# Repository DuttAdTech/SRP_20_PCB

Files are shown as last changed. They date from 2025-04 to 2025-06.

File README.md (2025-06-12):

### Changes Suggested by Team
- Add Debug Headers for UART Lines for GSM.
- LORA Module Footprint adjust for Hand Soldering.
- Check SRAM Compatibility - 2 MBit.
- Add Resettable Fuse after SM712 Protection Diode on MB Lines.
- Display connector change in PCB.
- PCB partision layer change (edge cut).
- Make LDO based power supply.
- SDA SCL of ADS1115 need to connected properly.
- Vbat pin of the battery measurement need to connected to the MCU.
- Add 100uF capacitor(x2) in GSM.
- Logic level shifter footprint should be SC70.
- Ground of the optocoupler and Trip should be different
- Voltage for the TFT display should be checked before doing PCB connections.

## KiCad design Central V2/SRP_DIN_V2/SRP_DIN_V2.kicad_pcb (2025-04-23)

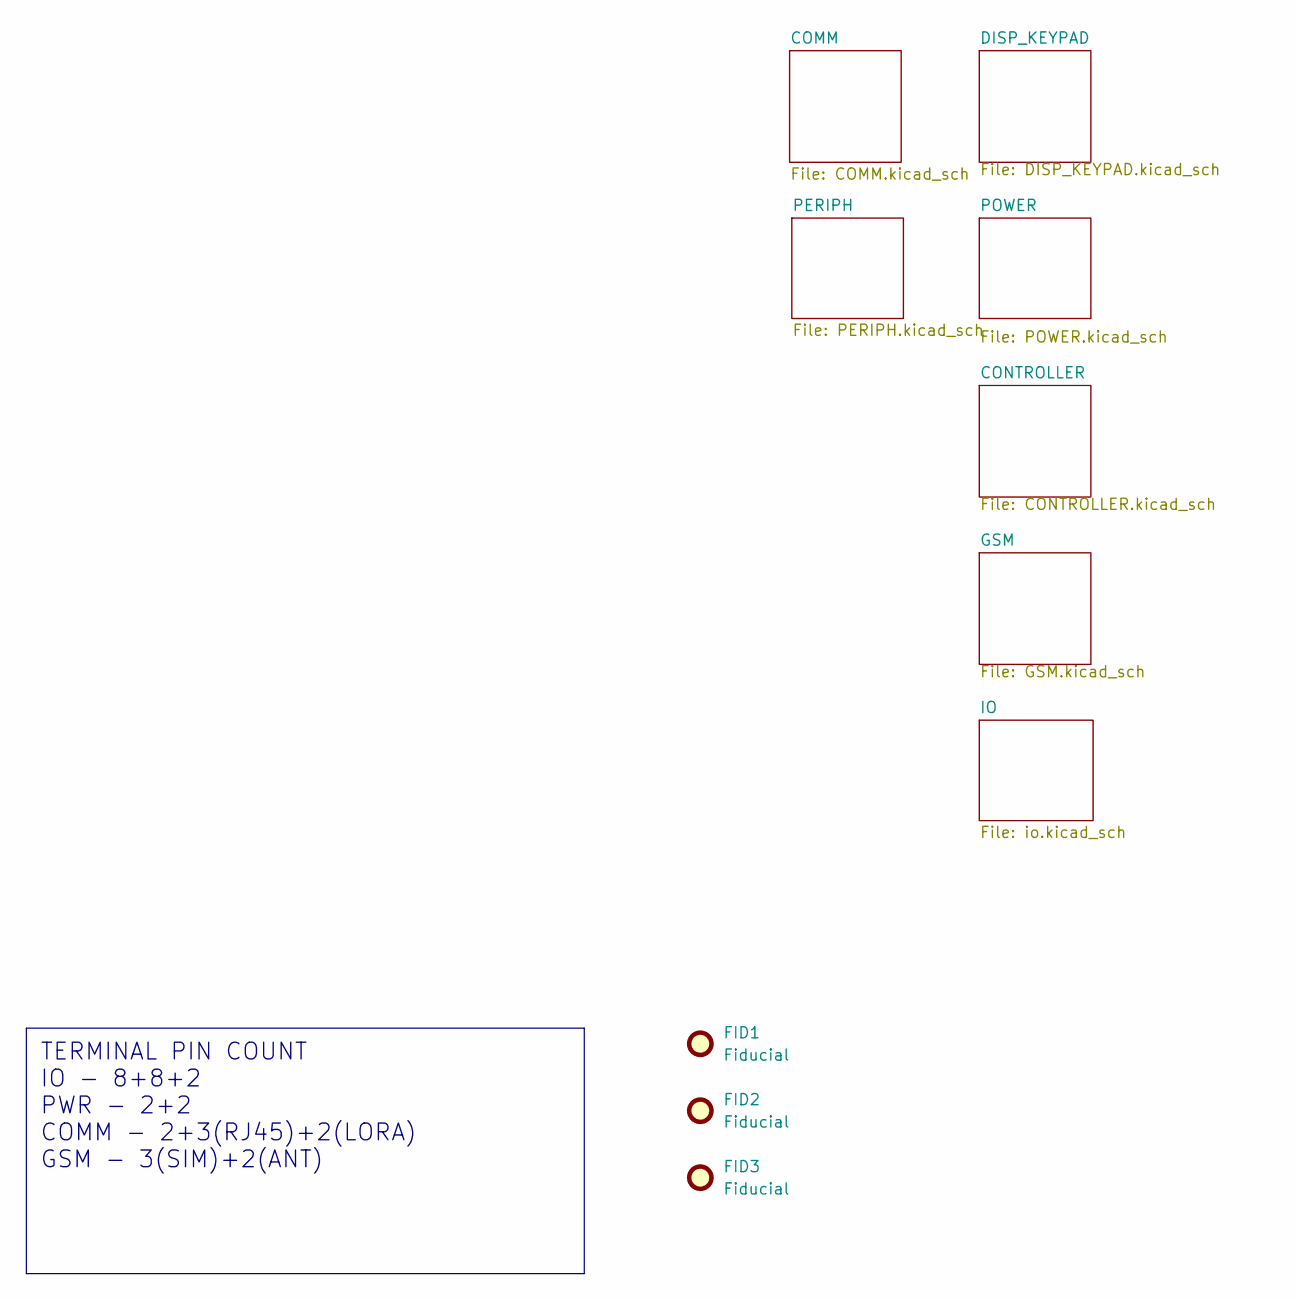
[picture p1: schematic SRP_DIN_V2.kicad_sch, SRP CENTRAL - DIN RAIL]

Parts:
FID1, FID2, FID3: Fiducial; Fiducial_1mm_Mask2mm

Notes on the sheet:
TERMINAL PIN COUNT IO - 8+8+2 PWR - 2+2 COMM - 2+3(RJ45)+2(LORA) GSM - 3(SIM)+2(ANT)

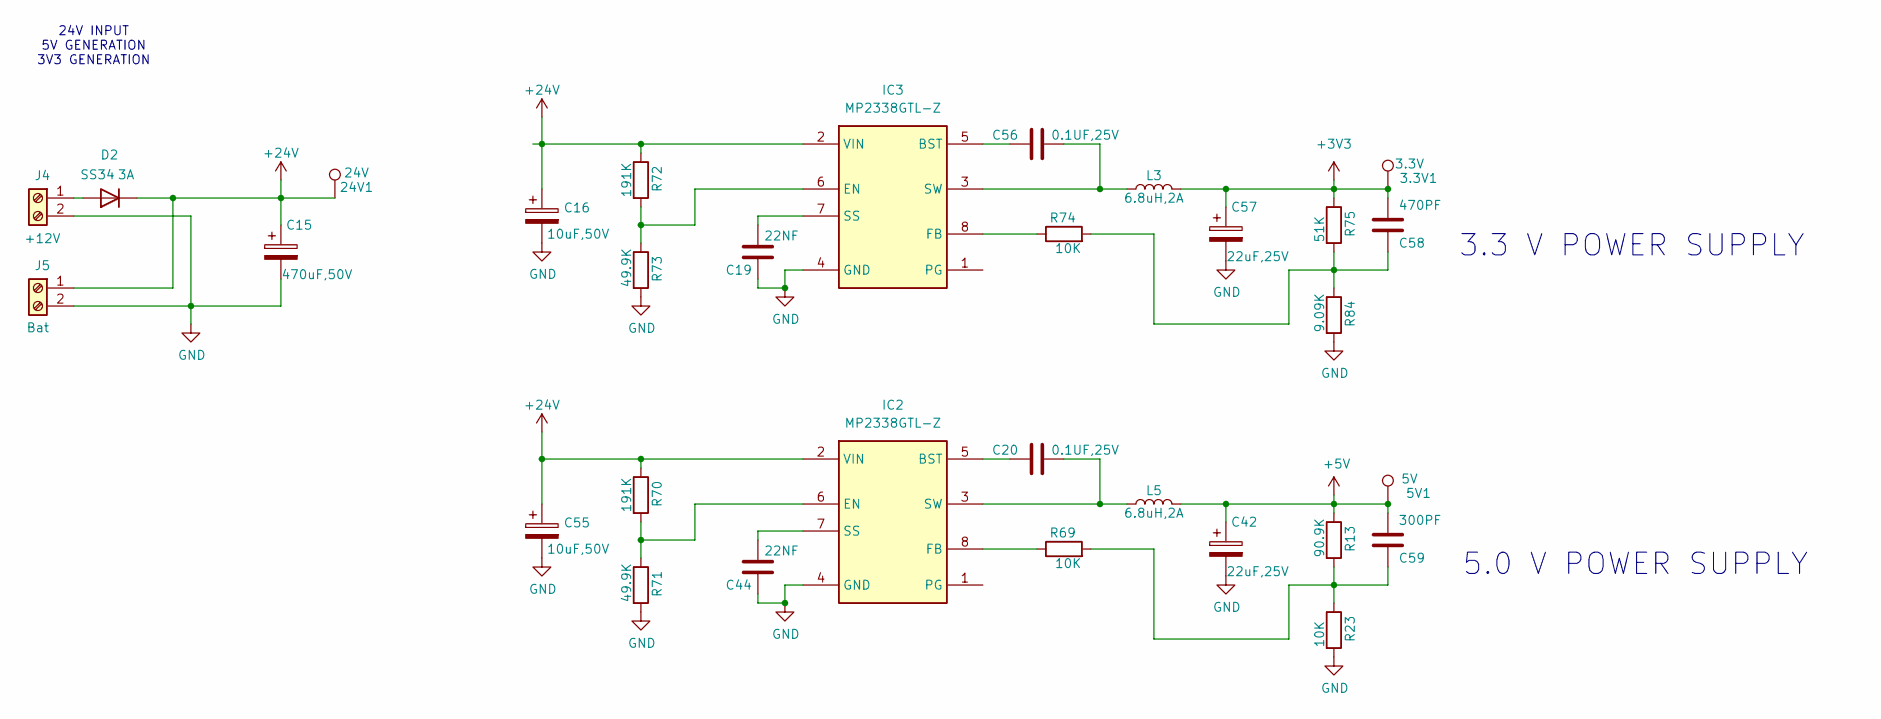
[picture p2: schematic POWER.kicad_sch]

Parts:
3.3V1: 3.3V; TestPoint_Pad_1.0x1.0mm
5V1: 5V; TestPoint_Pad_1.0x1.0mm
24V1: 24V; TestPoint_Pad_1.0x1.0mm
C15: 470uF,50V; CP_Elec_10x10.5
C16, C55: 10uF,50V; CP_Elec_8x5.4
C19, C44: 22NF; C_0805_2012Metric
C20, C56: 0.1UF,25V; C_0805_2012Metric
C42, C57: 22uF,25V; CP_Elec_6.3x5.3
C58: 470PF; C_0805_2012Metric
C59: 300PF; C_0805_2012Metric
D2: SS34; D_SMA
IC2, IC3: MP2338GTL-Z; SOT-583-8; Mouser Part Number 946-MP2338GTL-Z
J4: +12V; TerminalBlock_Phoenix_MKDS-3-2-5.08_1x02_P5.08mm_Horizontal
J5: Bat; TerminalBlock_Phoenix_MKDS-3-2-5.08_1x02_P5.08mm_Horizontal
L3, L5: 6.8uH,2A; L_2010_5025Metric
R13: 90.9K; R_0805_2012Metric_Pad1.20x1.40mm_HandSolder
R23, R69, R74: 10K; R_0805_2012Metric_Pad1.20x1.40mm_HandSolder
R70, R72: 191K; R_0805_2012Metric_Pad1.20x1.40mm_HandSolder
R71, R73: 49.9K; R_0805_2012Metric_Pad1.20x1.40mm_HandSolder
R75: 51K; R_0805_2012Metric_Pad1.20x1.40mm_HandSolder
R84: 9.09K; R_0805_2012Metric_Pad1.20x1.40mm_HandSolder

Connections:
+3V3: 3.3V1.1, C57.1, C58.2, L3.2, R75.1; also elsewhere on the board
+5V: 5V1.1, C42.1, C59.2, L5.2, R13.1; also elsewhere on the board
+24V: 24V1.1, C15.1, C16.1, C55.1, D2.1 (K), IC2.2 (VIN), IC3.2 (VIN), J5.1, R70.1, R72.1; also elsewhere on the board
GND: C15.2, C16.2, C19.1, C42.2, C44.1, C55.2, C57.2, IC2.4 (GND), IC3.4 (GND), J4.2, J5.2, R23.2, R71.2, R73.2, R84.2; also elsewhere on the board
unnamed: C58.1, R74.2, R75.2, R84.1
unnamed: C59.1, R13.2, R23.1, R69.2
unnamed: D2.2 (A), J4.1
unnamed: C20.1, IC2.5 (BST)
unnamed: IC2.6 (EN), R70.2, R71.1
unnamed: IC2.8 (FB), R69.1
unnamed: C44.2, IC2.7 (SS)
unnamed: C20.2, IC2.3 (SW), L5.1
unnamed: C56.1, IC3.5 (BST)
unnamed: IC3.6 (EN), R72.2, R73.1
unnamed: IC3.8 (FB), R74.1
unnamed: C19.2, IC3.7 (SS)
unnamed: C56.2, IC3.3 (SW), L3.1

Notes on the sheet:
3.3 V POWER SUPPLY
5.0 V POWER SUPPLY
24V INPUT 5V GENERATION 3V3 GENERATION

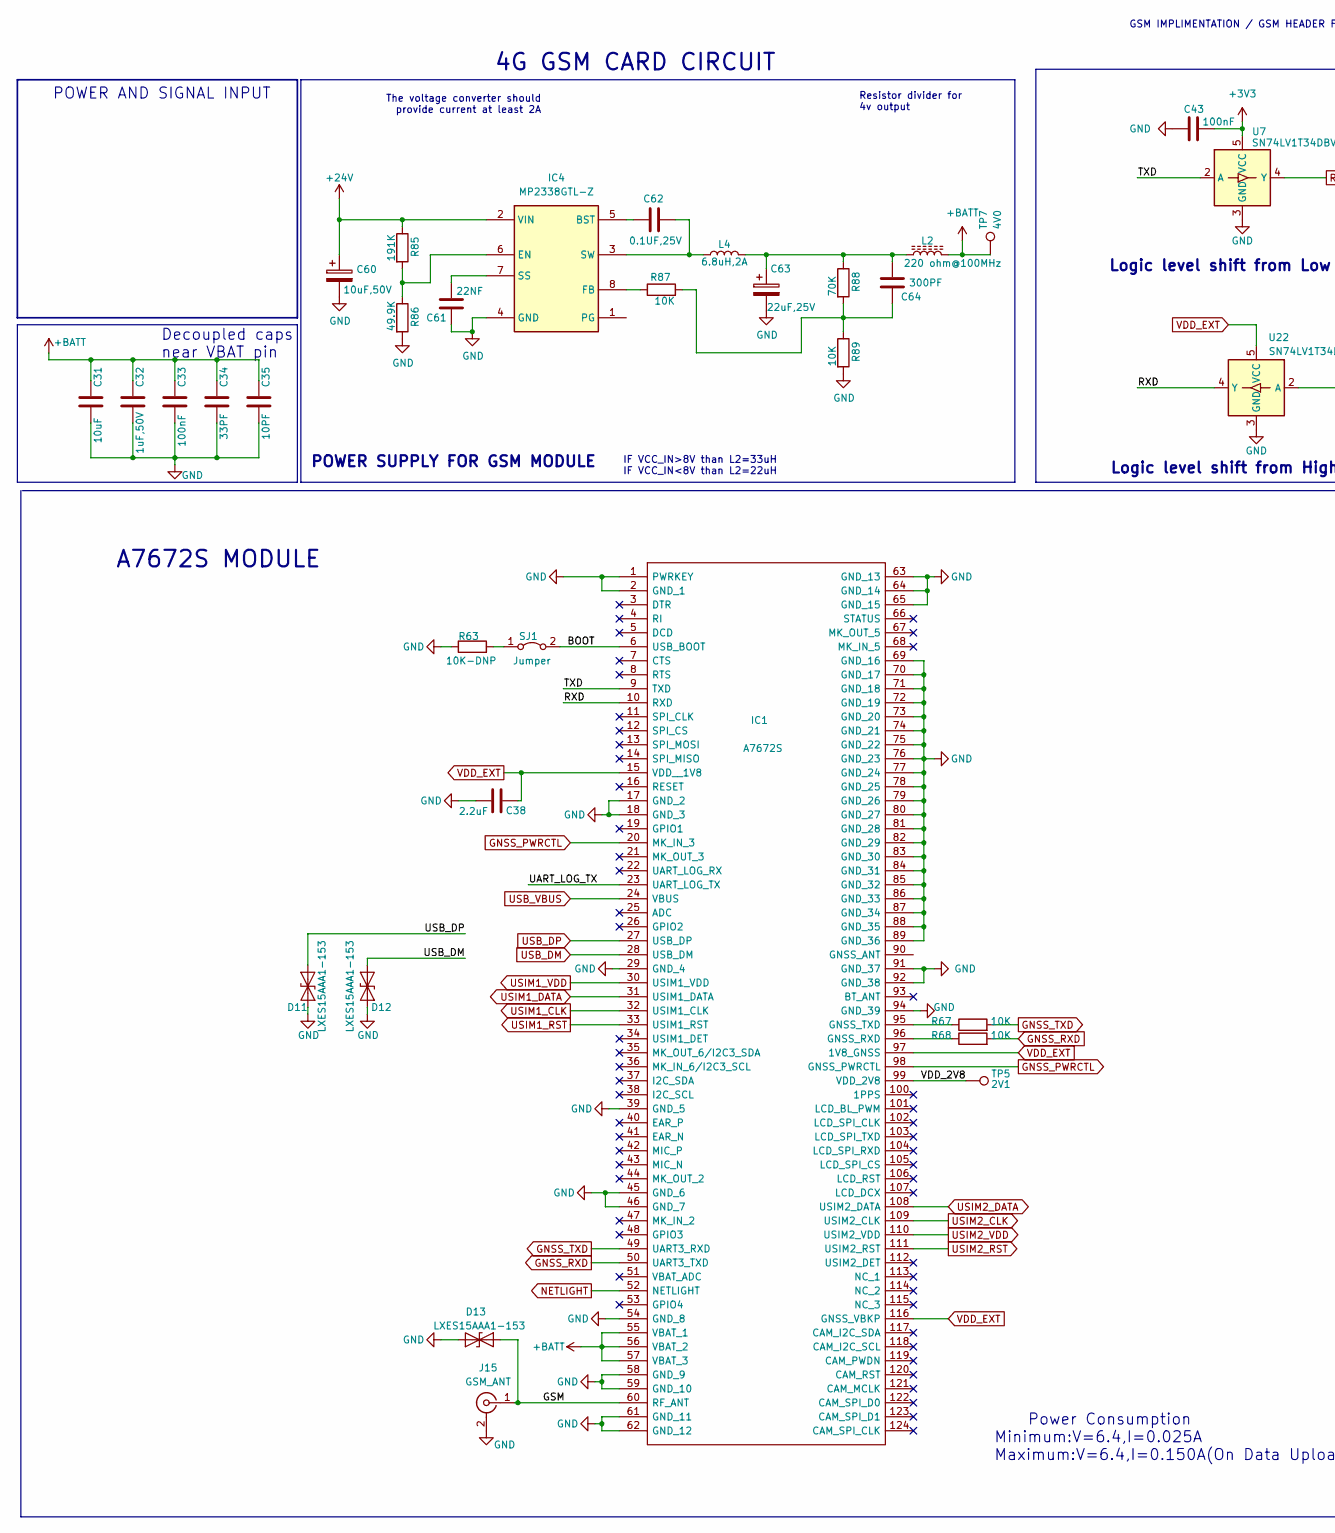
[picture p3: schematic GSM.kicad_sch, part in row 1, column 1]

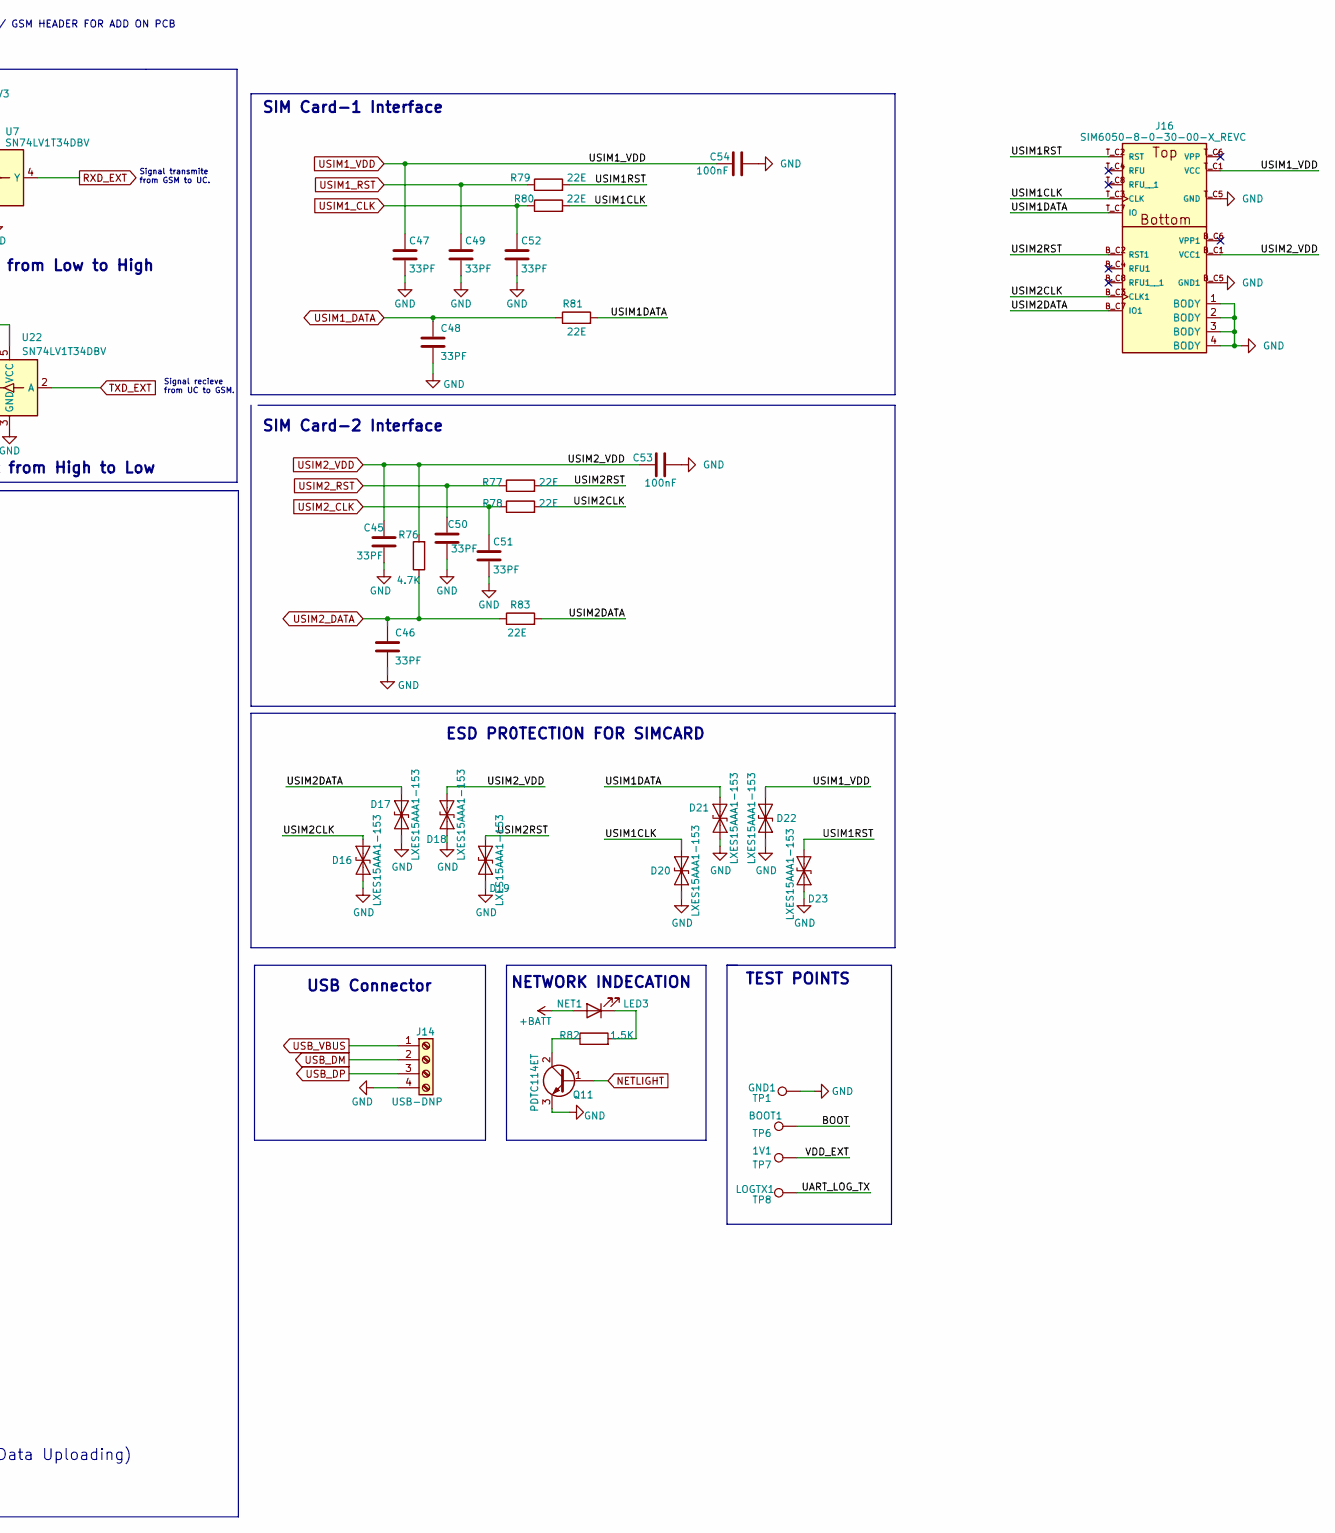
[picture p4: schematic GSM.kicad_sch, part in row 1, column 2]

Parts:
1V1, 4V0: TP7; TestPoint_Pad_1.0x1.0mm
2V1: TP5; TestPoint_Pad_1.0x1.0mm
BOOT1: TP6; TestPoint_Pad_1.0x1.0mm
C31: 10uF; C_0805_2012Metric
C32: 1uF,50V; C_0805_2012Metric
C33, C43, C53, C54: 100nF; C_0805_2012Metric
C34, C45, C46, C47, C48, C49, C50, C51, C52: 33PF; C_0805_2012Metric
C35: 10PF; C_0805_2012Metric
C38: 2.2uF; C_0805_2012Metric
C60: 10uF,50V; CP_Elec_6.3x5.3
C61: 22NF; C_0805_2012Metric
C62: 0.1UF,25V; C_0805_2012Metric
C63: 22uF,25V; CP_Elec_6.3x5.3
C64: 300PF; C_0805_2012Metric
D11, D12, D13, D16, D17, D18, D19, D20, D21, D22, D23: LXES15AAA1-153; D_0402_1005Metric_Pad0.77x0.64mm_HandSolder
GND1: TP1; TestPoint_Pad_1.0x1.0mm
IC1: A7672S; A7672SA; Manufacturer_Part_Number A7672SA
IC4: MP2338GTL-Z; SOT-583-8; Mouser Part Number 946-MP2338GTL-Z
J14: USB-DNP; PinHeader_1x04_P2.54mm_Vertical
J15: GSM_ANT; SMA_Amphenol_901-144_Vertical
J16: SIM6050-8-0-30-00-X_REVC; GCT_SIM6050-8-0-30-00-X_REVC
L2: 220 ohm@100MHz; L_0805_2012Metric
L4: 6.8uH,2A; L_2010_5025Metric
LOGTX1: TP8; TestPoint_Pad_1.0x1.0mm
NET1: LED3; LED_0805_2012Metric_Pad1.15x1.40mm_HandSolder
Q11: PDTC114ET; SOT-23
R63: 10K-DNP; R_0805_2012Metric
R67, R68: 10K; R_0805_2012Metric
R76: 4.7K; R_0805_2012Metric
R77, R78, R79, R80, R81, R83: 22E; R_0805_2012Metric
R82: 1.5K; R_0805_2012Metric
R85: 191K; R_0805_2012Metric_Pad1.20x1.40mm_HandSolder
R86: 49.9K; R_0805_2012Metric_Pad1.20x1.40mm_HandSolder
R87, R89: 10K; R_0805_2012Metric_Pad1.20x1.40mm_HandSolder
R88: 70K; R_0805_2012Metric_Pad1.20x1.40mm_HandSolder
SJ1: Jumper; SolderJumper-2_P1.3mm_Open_Pad1.0x1.5mm
U7, U22: SN74LV1T34DBV; SOT-23-5

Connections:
+3V3: C43.2, U7.5 (VCC); also elsewhere on the board
+24V: C60.1, IC4.2 (VIN), R85.1; also elsewhere on the board
+BATT: 4V0.1, C31.1, C32.1, C33.1, C34.1, C35.1, IC1.55 (VBAT_1), IC1.56 (VBAT_2), IC1.57 (VBAT_3), L2.2, NET1.2 (A)
/GSM/BOOT: BOOT1.1, IC1.6 (USB_BOOT), SJ1.2 (B)
/GSM/GSM: D13.1 (A1), IC1.60 (RF_ANT), J15.1 (In)
/GSM/RXD: IC1.10 (RXD), U22.4 (Y)
/GSM/TXD: IC1.9 (TXD), U7.2 (A)
/GSM/UART_LOG_TX: IC1.23 (UART_LOG_TX), LOGTX1.1
/GSM/USIM1CLK: D20.2 (A2), J16.T_C3 (CLK), R80.2
/GSM/USIM1DATA: D21.2 (A2), J16.T_C7 (IO), R81.2
/GSM/USIM1RST: D23.2 (A2), J16.T_C2 (RST), R79.2
/GSM/USIM2CLK: D16.2 (A2), J16.B_C3 (CLK1), R78.2
/GSM/USIM2DATA: D17.2 (A2), J16.B_C7 (IO1), R83.2
/GSM/USIM2RST: D19.2 (A2), J16.B_C2 (RST1), R77.2
/GSM/VDD_2V8: 2V1.1, IC1.99 (VDD_2V8)
GND: C31.2, C32.2, C33.2, C34.2, C35.2, C38.2, C43.1, C45.2, C46.2, C47.2, C48.2, C49.2, C50.2, C51.2, C52.2, C53.2, C54.2, C60.2, C61.1, C63.2, D11.1 (A1), D12.1 (A1), D13.2 (A2), D16.1 (A1), D17.1 (A1), D18.1 (A1), D19.1 (A1), D20.1 (A1), D21.1 (A1), D22.1 (A1), D23.1 (A1), GND1.1, IC1.1 (PWRKEY), IC1.2 (GND_1), IC1.17 (GND_2), IC1.18 (GND_3), IC1.29 (GND_4), IC1.39 (GND_5), IC1.45 (GND_6), IC1.46 (GND_7), IC1.54 (GND_8), IC1.58 (GND_9), IC1.59 (GND_10), IC1.61 (GND_11), IC1.62 (GND_12), IC1.63 (GND_13), IC1.64 (GND_14), IC1.65 (GND_15), IC1.69 (GND_16), IC1.70 (GND_17), IC1.71 (GND_18), IC1.72 (GND_19), IC1.73 (GND_20), IC1.74 (GND_21), IC1.75 (GND_22), IC1.76 (GND_23), IC1.77 (GND_24), IC1.78 (GND_25), IC1.79 (GND_26), IC1.80 (GND_27), IC1.81 (GND_28), IC1.82 (GND_29), IC1.83 (GND_30), IC1.84 (GND_31), IC1.85 (GND_32), IC1.86 (GND_33), IC1.87 (GND_34), IC1.88 (GND_35), IC1.89 (GND_36), IC1.91 (GND_37), IC1.92 (GND_38), IC1.94 (GND_39), IC4.4 (GND), J14.4, J15.2 (Ext), J16.1 (BODY), J16.2 (BODY), J16.3 (BODY), J16.4 (BODY), J16.B_C5 (GND1), J16.T_C5 (GND), Q11.3 (E), R63.1, R86.2, R89.2, U7.3 (GND), U22.3 (GND); also elsewhere on the board
GNSS_PWRCTL: IC1.20 (MK_IN_3), IC1.98 (GNSS_PWRCTL)
GNSS_RXD: IC1.50 (UART3_TXD), R68.2
GNSS_TXD: IC1.49 (UART3_RXD), R67.2
NETLIGHT: IC1.52 (NETLIGHT), Q11.1 (B)
unnamed: C63.1, C64.2, L2.1, L4.2, R88.1
unnamed: C64.1, R87.2, R88.2, R89.1
unnamed: IC1.96 (GNSS_RXD), R68.1
unnamed: IC1.95 (GNSS_TXD), R67.1
unnamed: C62.1, IC4.5 (BST)
unnamed: IC4.6 (EN), R85.2, R86.1
unnamed: IC4.8 (FB), R87.1
unnamed: C61.2, IC4.7 (SS)
unnamed: C62.2, IC4.3 (SW), L4.1
unnamed: NET1.1 (K), R82.2
unnamed: Q11.2 (C), R82.1
unnamed: R63.2, SJ1.1 (A)
RXD_EXT: U7.4 (Y); also elsewhere on the board
TXD_EXT: U22.2 (A); also elsewhere on the board
USB_DM: D12.2 (A2), IC1.28 (USB_DM), J14.2
USB_DP: D11.2 (A2), IC1.27 (USB_DP), J14.3
USB_VBUS: IC1.24 (VBUS), J14.1
USIM1_CLK: C52.1, IC1.32 (USIM1_CLK), R80.1
USIM1_DATA: C48.1, IC1.31 (USIM1_DATA), R81.1
USIM1_RST: C49.1, IC1.33 (USIM1_RST), R79.1
USIM1_VDD: C47.1, C54.1, D22.2 (A2), IC1.30 (USIM1_VDD), J16.T_C1 (VCC)
USIM2_CLK: C51.1, IC1.109 (USIM2_CLK), R78.1
USIM2_DATA: C46.1, IC1.108 (USIM2_DATA), R76.1, R83.1
USIM2_RST: C50.1, IC1.111 (USIM2_RST), R77.1
USIM2_VDD: C45.1, C53.1, D18.2 (A2), IC1.110 (USIM2_VDD), J16.B_C1 (VCC1), R76.2
VDD_EXT: 1V1.1, C38.1, IC1.15 (VDD__1V8), IC1.97 (1V8_GNSS), IC1.116 (GNSS_VBKP), U22.5 (VCC)

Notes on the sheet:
NETWORK INDECATION
TEST POINTS
ESD PR0TECTION FOR SIMCARD
Logic level shift from High to Low
4G GSM CARD CIRCUIT
SIM Card-2 Interface
Signal transmite from GSM to UC.
Logic level shift from Low to High
A7672S MODULE
The voltage converter should provide current at least 2A
Resistor divider for 4v output
POWER SUPPLY FOR GSM MODULE
Signal recieve from UC to GSM.
GSM IMPLIMENTATION / GSM HEADER FOR ADD ON PCB
Power Consumption Minimum:V=6.4,I=0.025A Maximum:V=6.4,I=0.150A(On Data Uploading)
IF VCC_IN>8V than L2=33uH IF VCC_IN<8V than L2=22uH
POWER AND SIGNAL INPUT
Decoupled caps near VBAT pin
SIM Card-1 Interface
USB Connector

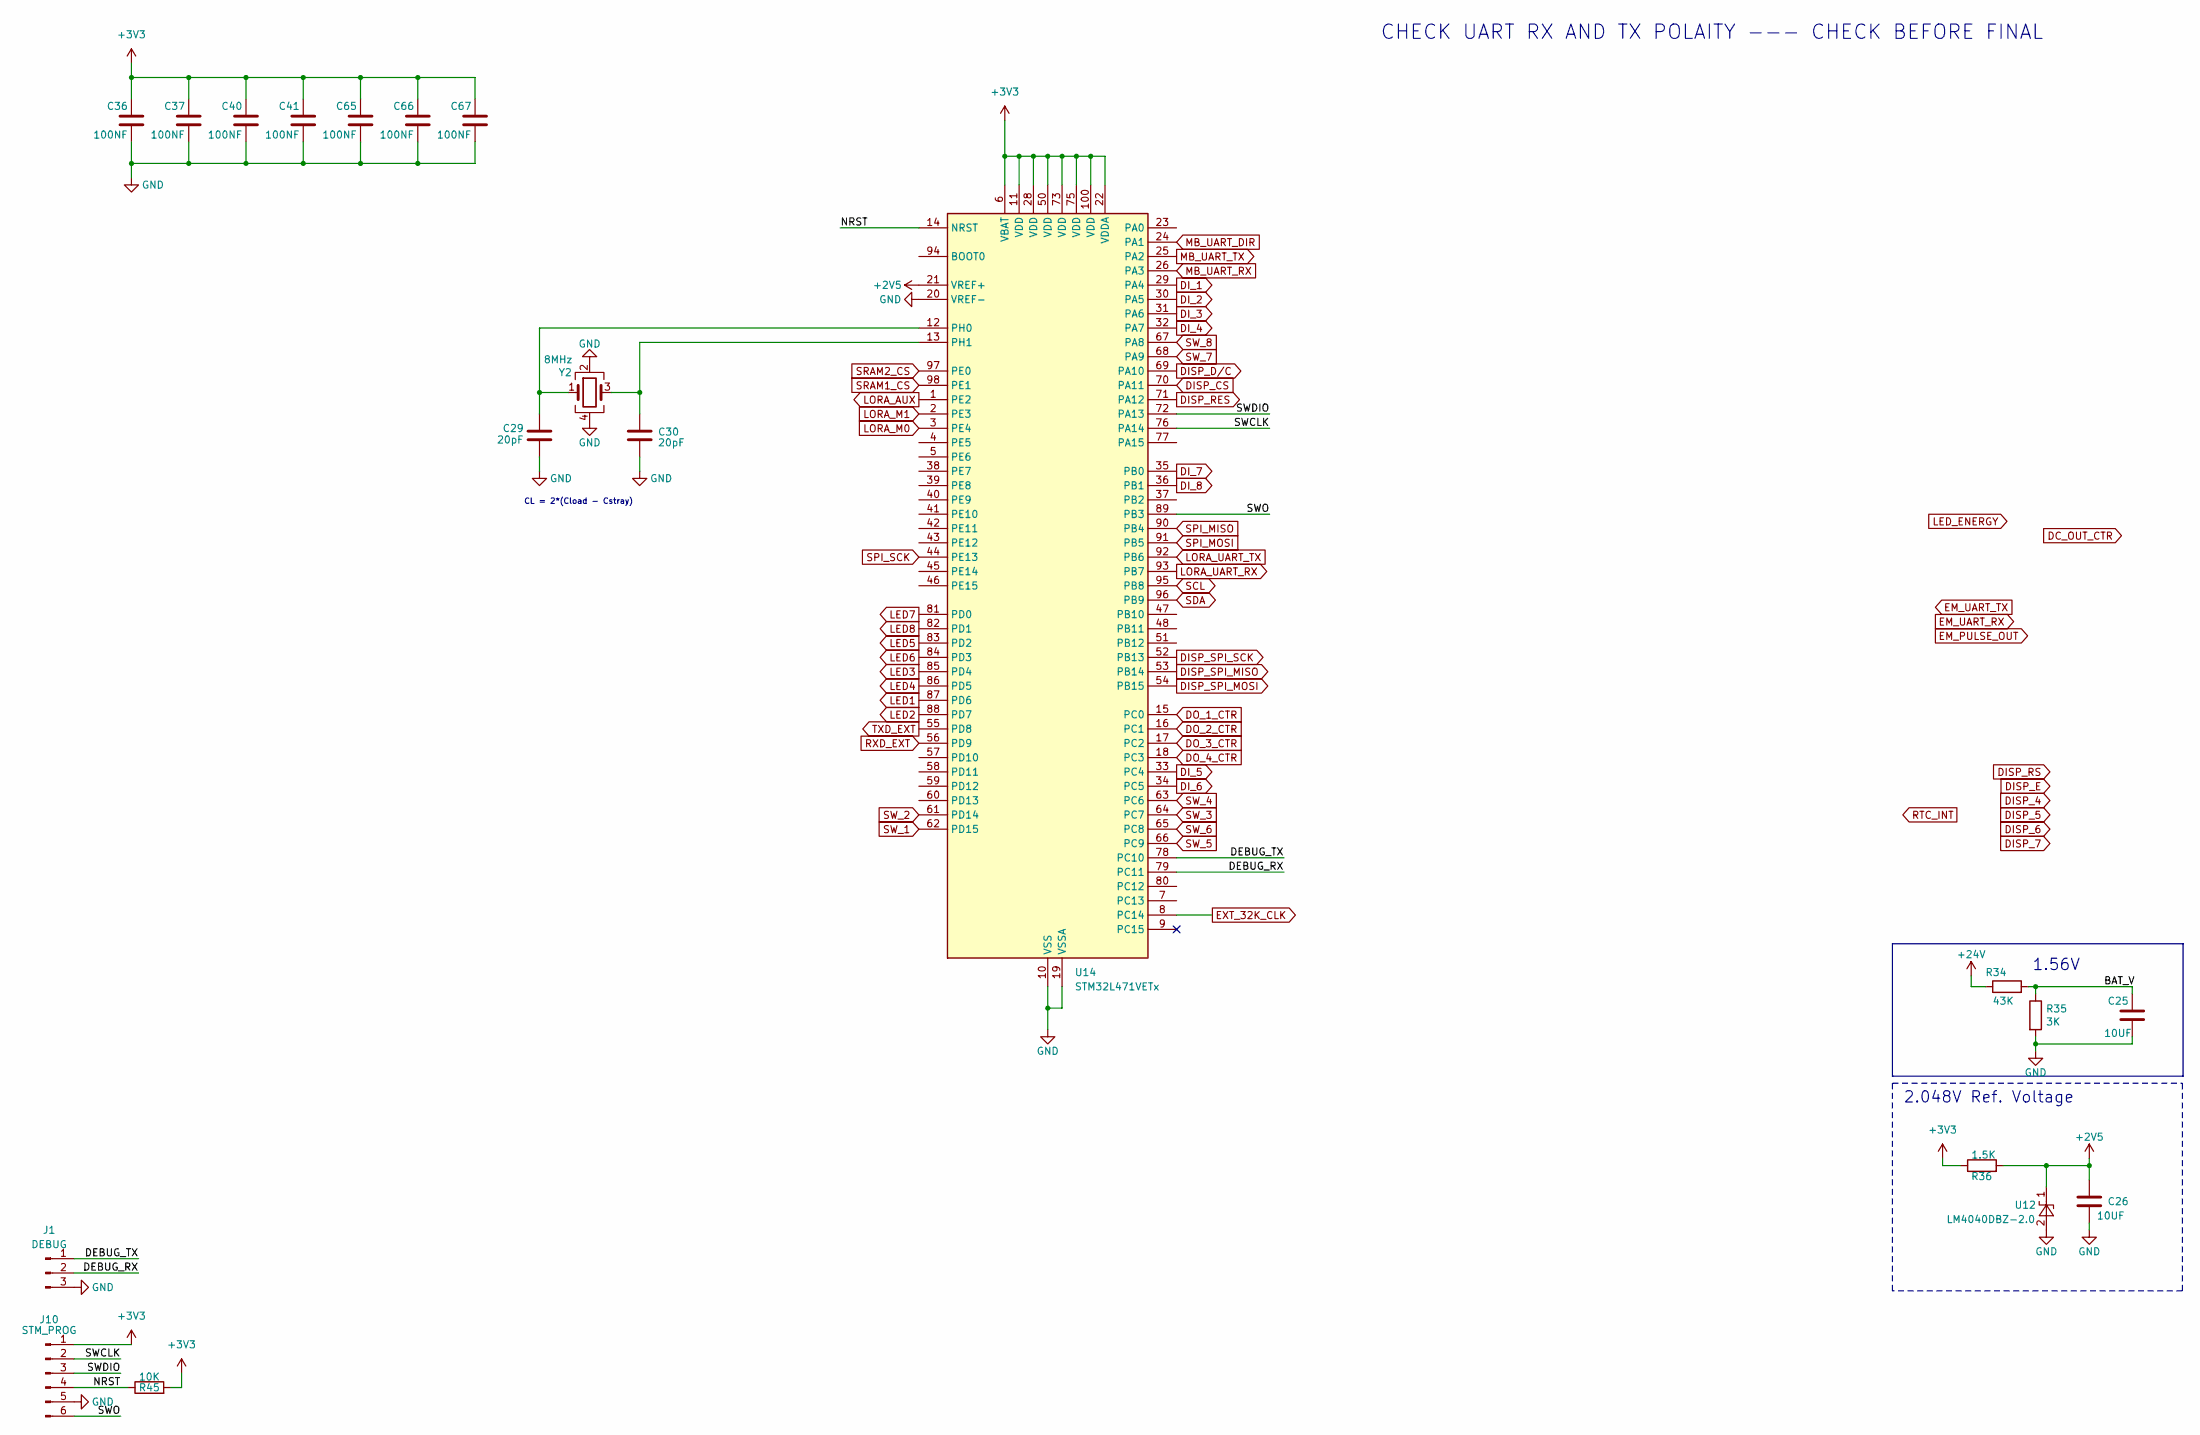
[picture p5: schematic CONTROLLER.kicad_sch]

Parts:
C25, C26: 10UF; C_0805_2012Metric
C29, C30: 20pF; C_0805_2012Metric
C36, C37, C40, C41, C65, C66, C67: 100NF; C_0805_2012Metric
J1: DEBUG; PinSocket_1x03_P2.54mm_Vertical
J10: STM_PROG; PinSocket_1x06_P2.54mm_Vertical
R34: 43K; R_0805_2012Metric
R35: 3K; R_0805_2012Metric
R36: 1.5K; R_0805_2012Metric
R45: 10K; R_0805_2012Metric
U12: LM4040DBZ-2.0; SOT-23
U14: STM32L471VETx; LQFP-100_14x14mm_P0.5mm
Y2: 8MHz; Crystal_SMD_Abracon_ABM3B-4Pin_5.0x3.2mm

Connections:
+2V5: C26.1, R36.2, U12.1 (K), U14.21 (VREF+)
+3V3: C36.1, C37.1, C40.1, C41.1, C65.1, C66.1, C67.1, J10.1, R36.1, R45.2, U14.6 (VBAT), U14.11 (VDD), U14.22 (VDDA), U14.28 (VDD), U14.50 (VDD), U14.73 (VDD), U14.75 (VDD), U14.100 (VDD); also elsewhere on the board
+24V: R34.1; also elsewhere on the board
/CONTROLLER/BAT_V: C25.1, R34.2, R35.1
/CONTROLLER/DEBUG_RX: J1.2, U14.79 (PC11)
/CONTROLLER/DEBUG_TX: J1.1, U14.78 (PC10)
/CONTROLLER/NRST: J10.4, R45.1, U14.14 (NRST)
/CONTROLLER/SWCLK: J10.2, U14.76 (PA14)
/CONTROLLER/SWDIO: J10.3, U14.72 (PA13)
/CONTROLLER/SWO: J10.6, U14.89 (PB3)
DISP_CS: U14.70 (PA11); also elsewhere on the board
DISP_D/C: U14.69 (PA10); also elsewhere on the board
DISP_RES: U14.71 (PA12); also elsewhere on the board
DISP_SPI_MISO: U14.53 (PB14)
DISP_SPI_MOSI: U14.54 (PB15); also elsewhere on the board
DISP_SPI_SCK: U14.52 (PB13); also elsewhere on the board
DI_1: U14.29 (PA4); also elsewhere on the board
DI_2: U14.30 (PA5); also elsewhere on the board
DI_3: U14.31 (PA6); also elsewhere on the board
DI_4: U14.32 (PA7); also elsewhere on the board
DI_5: U14.33 (PC4); also elsewhere on the board
DI_6: U14.34 (PC5); also elsewhere on the board
DI_7: U14.35 (PB0); also elsewhere on the board
DI_8: U14.36 (PB1); also elsewhere on the board
DO_1_CTR: U14.15 (PC0); also elsewhere on the board
DO_2_CTR: U14.16 (PC1); also elsewhere on the board
DO_3_CTR: U14.17 (PC2); also elsewhere on the board
DO_4_CTR: U14.18 (PC3); also elsewhere on the board
EXT_32K_CLK: U14.8 (PC14); also elsewhere on the board
GND: C25.2, C26.2, C29.2, C30.2, C36.2, C37.2, C40.2, C41.2, C65.2, C66.2, C67.2, J1.3, J10.5, R35.2, U12.2 (A), U14.10 (VSS), U14.19 (VSSA), U14.20 (VREF-), U14.27 (VSS), U14.49 (VSS), U14.74 (VSS), U14.99 (VSS), Y2.2, Y2.4; also elsewhere on the board
LED1: U14.87 (PD6); also elsewhere on the board
LED2: U14.88 (PD7); also elsewhere on the board
LED3: U14.85 (PD4); also elsewhere on the board
LED4: U14.86 (PD5); also elsewhere on the board
LED5: U14.83 (PD2); also elsewhere on the board
LED6: U14.84 (PD3); also elsewhere on the board
LED7: U14.81 (PD0); also elsewhere on the board
LED8: U14.82 (PD1); also elsewhere on the board
LORA_AUX: U14.1 (PE2); also elsewhere on the board
LORA_M0: U14.3 (PE4); also elsewhere on the board
LORA_M1: U14.2 (PE3); also elsewhere on the board
LORA_UART_RX: U14.93 (PB7); also elsewhere on the board
LORA_UART_TX: U14.92 (PB6); also elsewhere on the board
MB_UART_DIR: U14.24 (PA1); also elsewhere on the board
MB_UART_RX: U14.26 (PA3); also elsewhere on the board
MB_UART_TX: U14.25 (PA2); also elsewhere on the board
unnamed: C29.1, U14.12 (PH0), Y2.1
unnamed: C30.1, U14.13 (PH1), Y2.3
RXD_EXT: U14.56 (PD9); also elsewhere on the board
SCL: U14.95 (PB8); also elsewhere on the board
SDA: U14.96 (PB9); also elsewhere on the board
SPI_MISO: U14.90 (PB4); also elsewhere on the board
SPI_MOSI: U14.91 (PB5); also elsewhere on the board
SPI_SCK: U14.44 (PE13); also elsewhere on the board
SRAM1_CS: U14.98 (PE1); also elsewhere on the board
SRAM2_CS: U14.97 (PE0); also elsewhere on the board
SW_1: U14.62 (PD15); also elsewhere on the board
SW_2: U14.61 (PD14); also elsewhere on the board
SW_3: U14.64 (PC7); also elsewhere on the board
SW_4: U14.63 (PC6); also elsewhere on the board
SW_5: U14.66 (PC9); also elsewhere on the board
SW_6: U14.65 (PC8); also elsewhere on the board
SW_7: U14.68 (PA9); also elsewhere on the board
SW_8: U14.67 (PA8); also elsewhere on the board
TXD_EXT: U14.55 (PD8); also elsewhere on the board

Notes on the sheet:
CHECK UART RX AND TX POLAITY --- CHECK BEFORE FINAL
CL = 2*(Cload - Cstray)
2.048V Ref. Voltage
1.56V

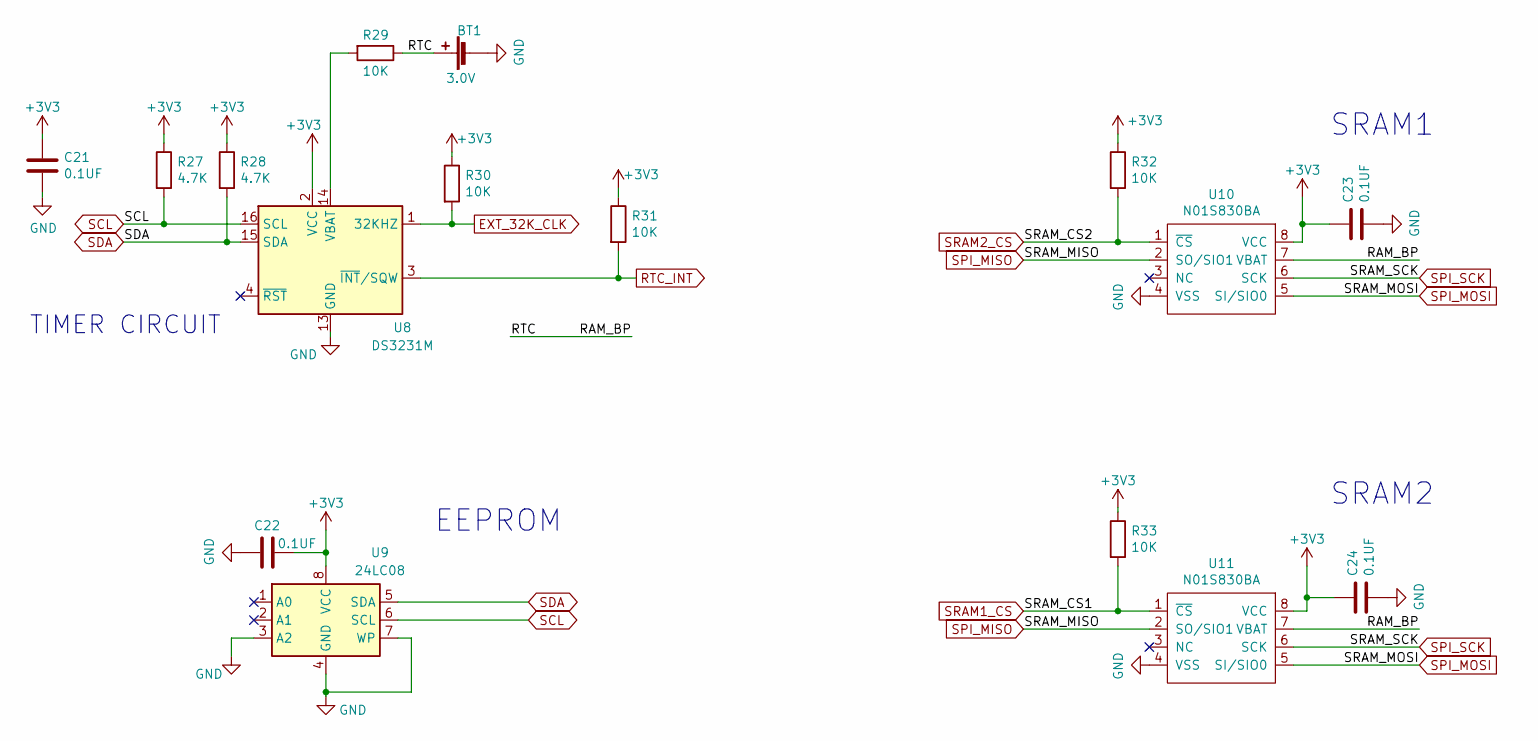
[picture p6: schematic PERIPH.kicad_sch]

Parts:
BT1: 3.0V; RTC_2032_VERTICLE_HOLDER
C21, C22, C23, C24: 0.1UF; C_0805_2012Metric
R27, R28: 4.7K; R_0805_2012Metric
R29, R30, R31, R32, R33: 10K; R_0805_2012Metric
U8: DS3231M; SOIC-16W_7.5x10.3mm_P1.27mm
U9: 24LC08; SOIC-8_3.9x4.9mm_P1.27mm
U10, U11: N01S830BA; TSSOP-8_4.4x3mm_P0.65mm

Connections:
+3V3: C21.1, C22.2, C23.1, C24.1, R27.1, R28.1, R30.1, R31.1, R32.1, R33.1, U8.2 (VCC), U9.8 (VCC), U10.8 (VCC), U11.8 (VCC); also elsewhere on the board
/PERIPH/RAM_BP: BT1.1 (+), R29.1, U10.7 (VBAT), U11.7 (VBAT)
EXT_32K_CLK: R30.2, U8.1 (32KHZ); also elsewhere on the board
GND: BT1.2 (-), C21.2, C22.1, C23.2, C24.2, U8.5 (GND), U8.6 (GND), U8.7 (GND), U8.8 (GND), U8.9 (GND), U8.10 (GND), U8.11 (GND), U8.12 (GND), U8.13 (GND), U9.3 (A2), U9.4 (GND), U9.7 (WP), U10.4 (VSS), U11.4 (VSS); also elsewhere on the board
unnamed: R29.2, U8.14 (VBAT)
RTC_INT: R31.2, U8.3 (~INT/SQW)
SCL: R27.2, U8.16 (SCL), U9.6 (SCL); also elsewhere on the board
SDA: R28.2, U8.15 (SDA), U9.5 (SDA); also elsewhere on the board
SPI_MISO: U10.2 (SO/SIO1), U11.2 (SO/SIO1); also elsewhere on the board
SPI_MOSI: U10.5 (SI/SIO0), U11.5 (SI/SIO0); also elsewhere on the board
SPI_SCK: U10.6 (SCK), U11.6 (SCK); also elsewhere on the board
SRAM1_CS: R33.2, U11.1 (~CS); also elsewhere on the board
SRAM2_CS: R32.2, U10.1 (~CS); also elsewhere on the board

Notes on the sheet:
SRAM1
SRAM2
TIMER CIRCUIT
EEPROM

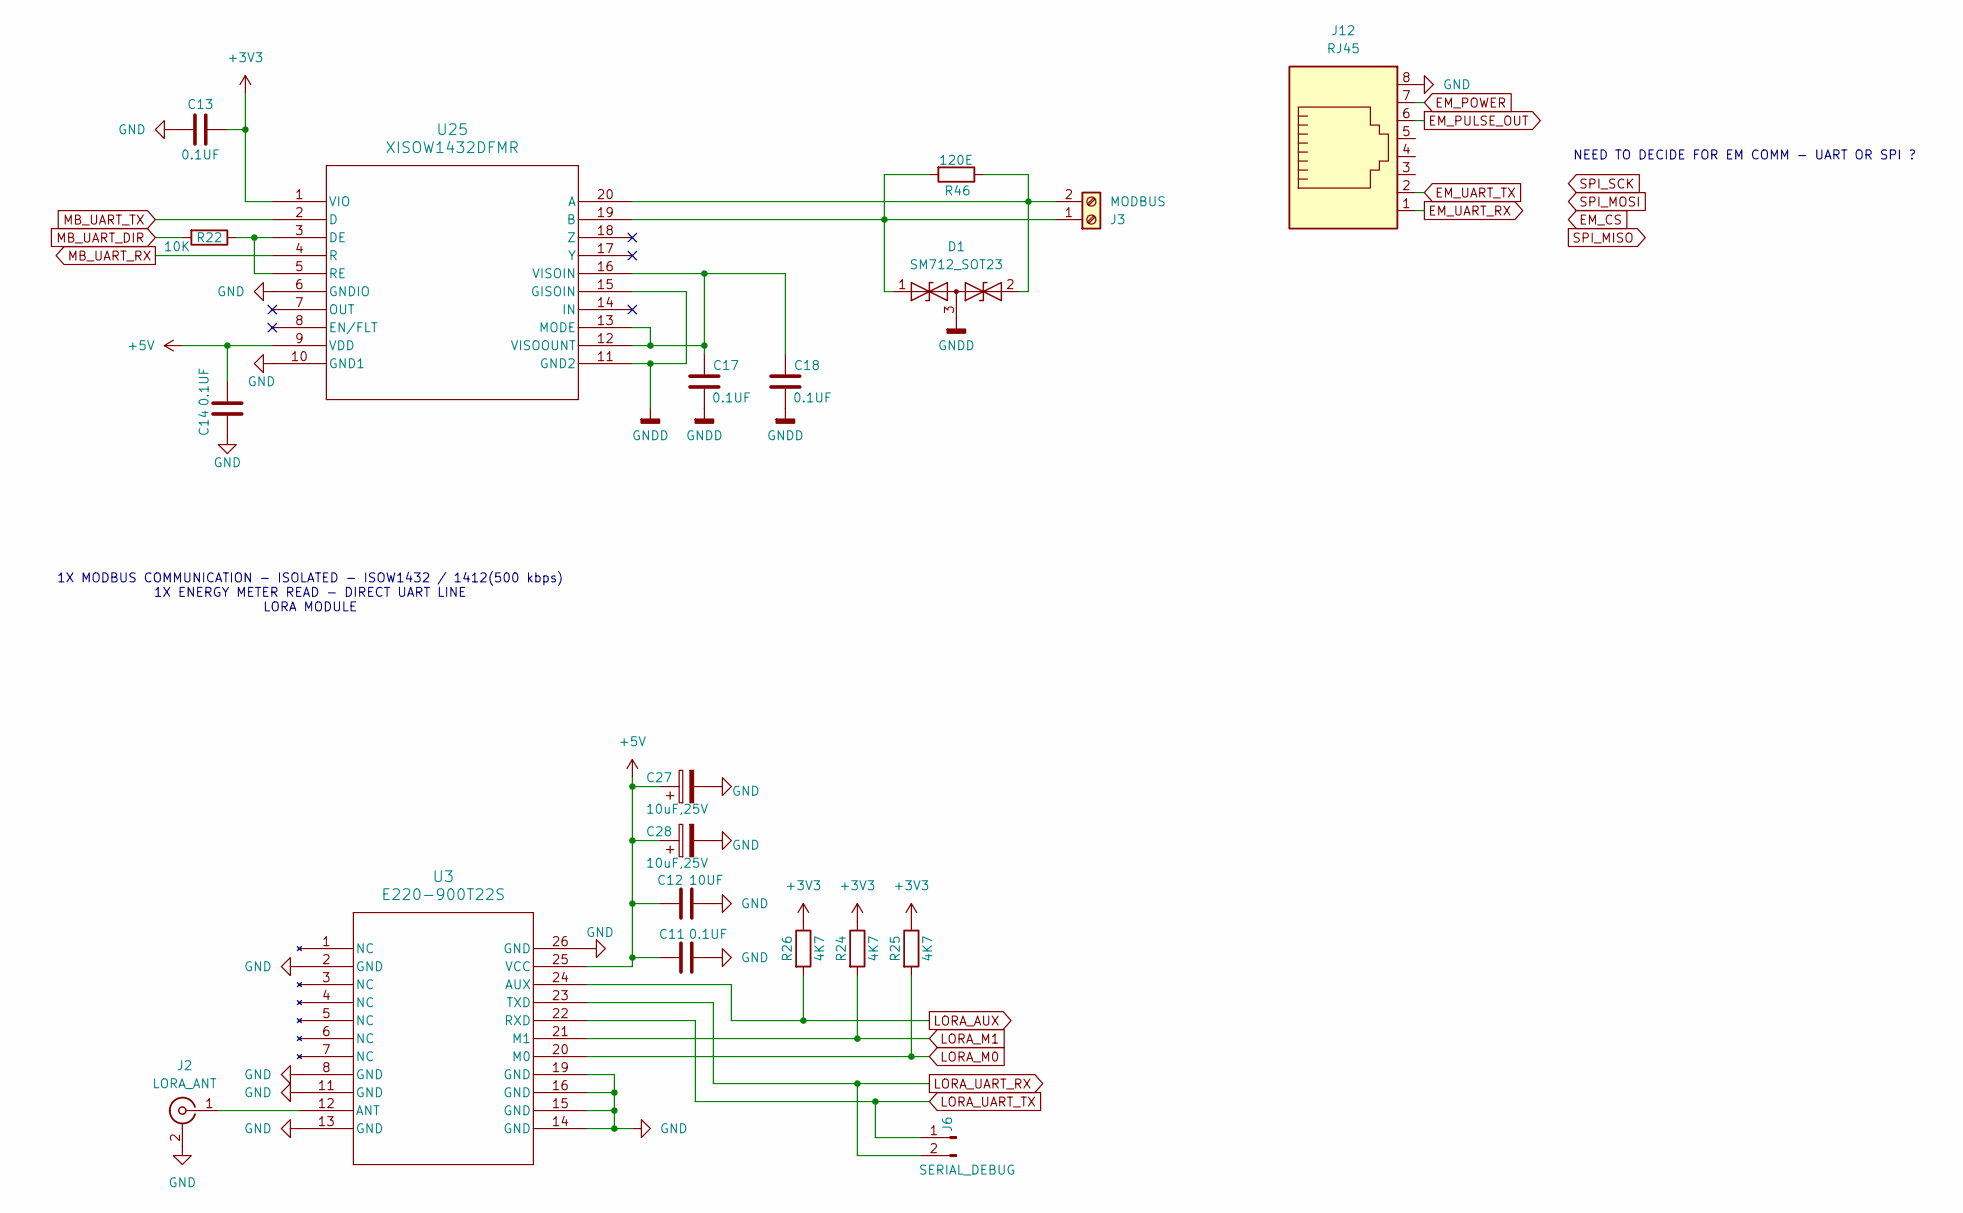
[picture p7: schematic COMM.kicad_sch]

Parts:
C11, C13, C14, C17, C18: 0.1UF; C_0805_2012Metric
C12: 10UF; C_0805_2012Metric
C27, C28: 10uF,25V; CP_Elec_4x5.4
D1: SM712_SOT23; SOT-23
J2: LORA_ANT; SMA_Amphenol_901-144_Vertical
J3: MODBUS; TerminalBlock_Phoenix_MKDS-3-2-5.08_1x02_P5.08mm_Horizontal
J6: SERIAL_DEBUG; PinSocket_1x02_P2.54mm_Vertical
J12: RJ45; RJ45_Amphenol_54602-x08_Horizontal
R22: 10K; R_0805_2012Metric
R24, R25, R26: 4K7; R_0805_2012Metric
R46: 120E; R_0805_2012Metric_Pad1.20x1.40mm_HandSolder
U3: E220-900T22S
U25: XISOW1432DFMR; U_ISOW1432_TEX

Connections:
+3V3: C13.1, R24.1, R25.1, R26.1, U25.1 (VIO); also elsewhere on the board
+5V: C11.1, C12.1, C14.2, C27.1, C28.1, U3.25 (VCC), U25.9 (VDD); also elsewhere on the board
EM_POWER: J12.7
EM_PULSE_OUT: J12.6
EM_UART_RX: J12.1
EM_UART_TX: J12.2
GND: C11.2, C12.2, C13.2, C14.1, C27.2, C28.2, J2.2 (Ext), J12.8, U3.2 (GND), U3.8 (GND), U3.11 (GND), U3.13 (GND), U3.14 (GND), U3.15 (GND), U3.16 (GND), U3.19 (GND), U3.26 (GND), U25.6 (GNDIO), U25.10 (GND1); also elsewhere on the board
GNDD: C17.1, C18.1, D1.3 (common), U25.11 (GND2), U25.15 (GISOIN)
LORA_AUX: R26.2, U3.24 (AUX); also elsewhere on the board
LORA_M0: R25.2, U3.20 (M0); also elsewhere on the board
LORA_M1: R24.2, U3.21 (M1); also elsewhere on the board
LORA_UART_RX: J6.2, U3.23 (TXD); also elsewhere on the board
LORA_UART_TX: J6.1, U3.22 (RXD); also elsewhere on the board
MB_UART_DIR: R22.2; also elsewhere on the board
MB_UART_RX: U25.4 (R); also elsewhere on the board
MB_UART_TX: U25.2 (D); also elsewhere on the board
unnamed: D1.1 (A1), J3.1, R46.2, U25.19 (B)
unnamed: D1.2 (A2), J3.2, R46.1, U25.20 (A)
unnamed: J2.1 (In), U3.12 (ANT)
unnamed: R22.1, U25.3 (DE), U25.5 (RE)
unnamed: C17.2, C18.2, U25.12 (VISOOUNT), U25.13 (MODE), U25.16 (VISOIN)

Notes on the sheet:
1X MODBUS COMMUNICATION - ISOLATED - ISOW1432 / 1412(500 kbps) 1X ENERGY METER READ - DIRECT UART LINE LORA MODULE
NEED TO DECIDE FOR EM COMM - UART OR SPI ?

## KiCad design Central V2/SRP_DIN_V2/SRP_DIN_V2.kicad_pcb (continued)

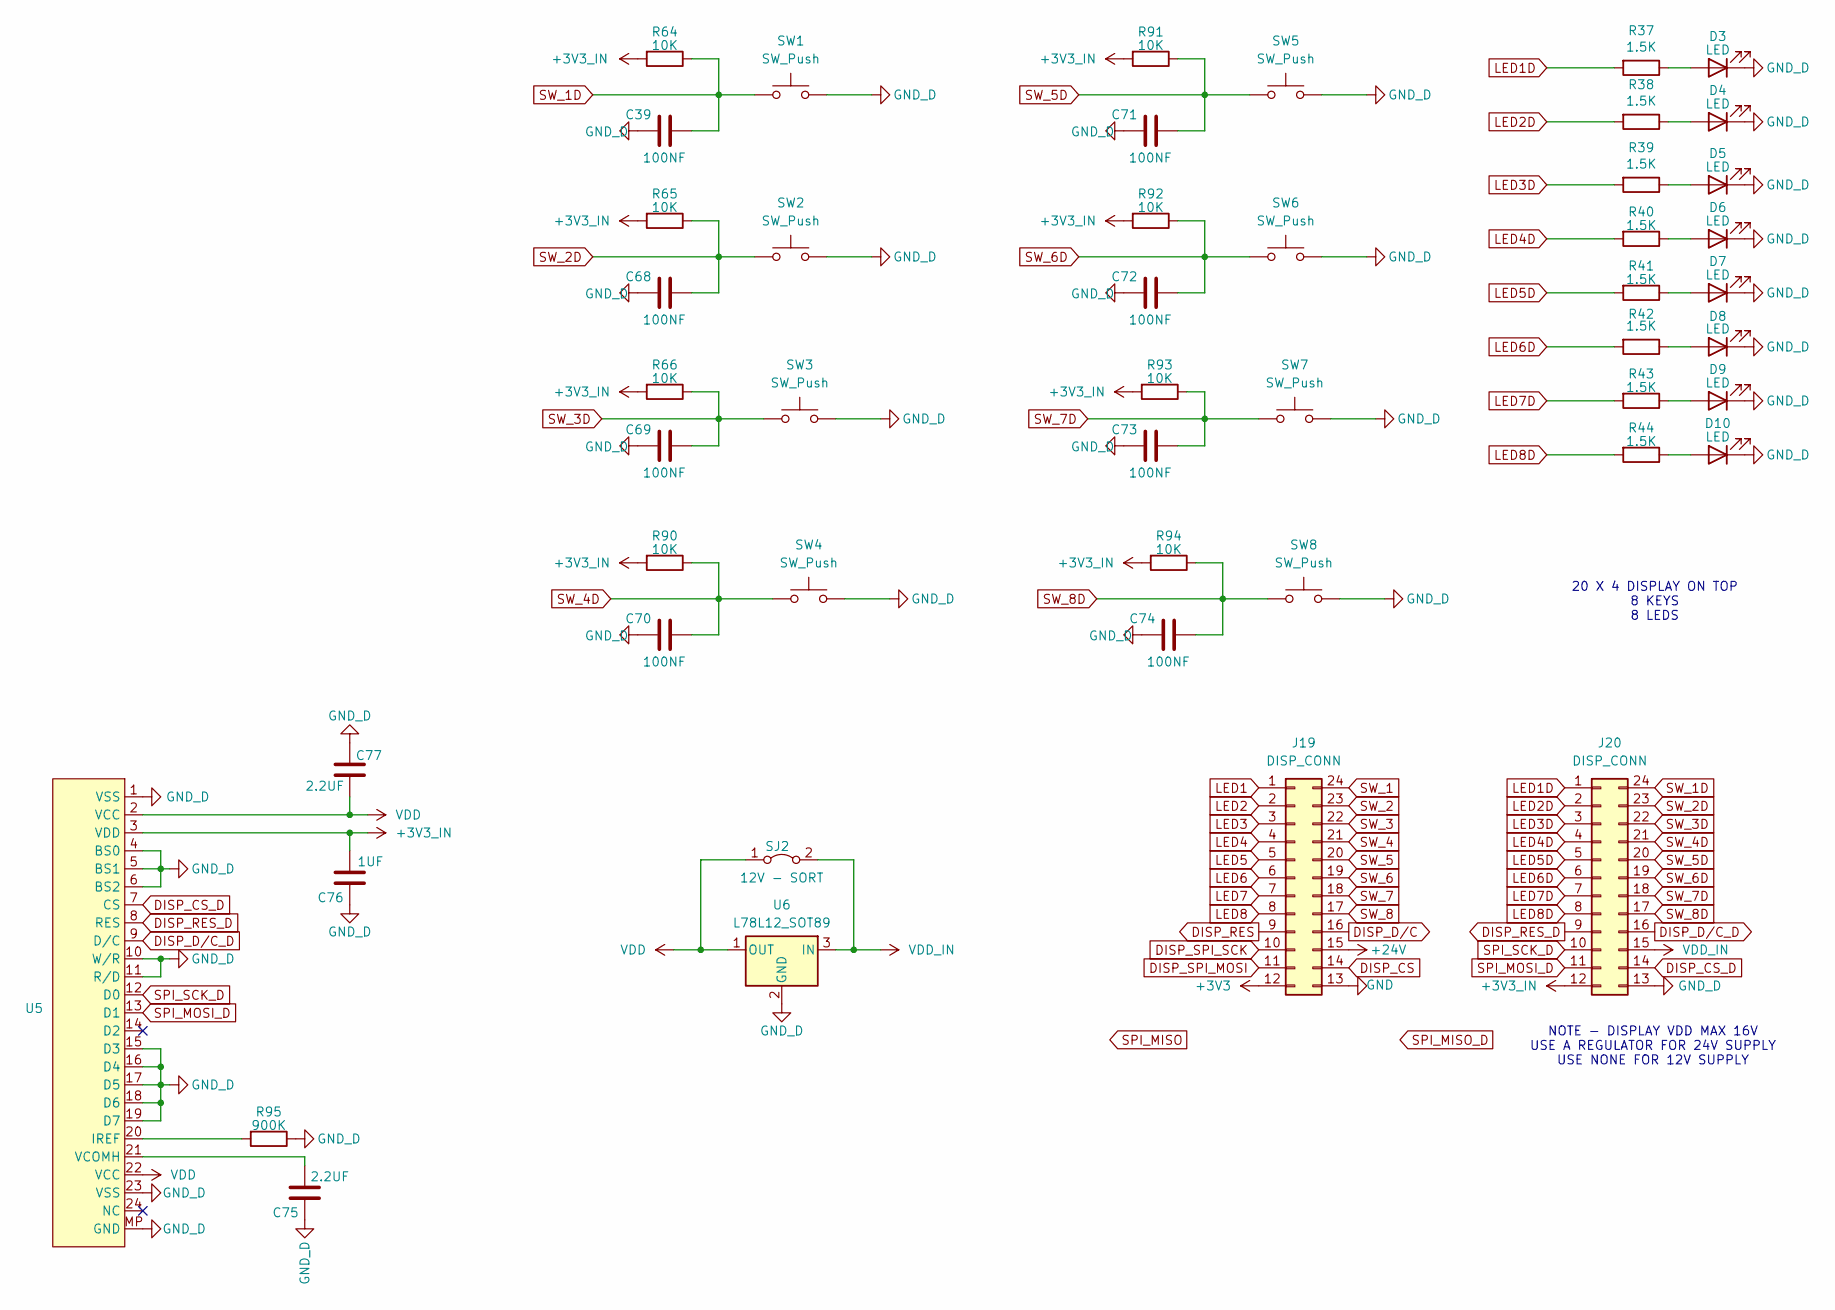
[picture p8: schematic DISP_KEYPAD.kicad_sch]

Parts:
C39, C68, C69, C70, C71, C72, C73, C74: 100NF; C_0805_2012Metric
C75, C77: 2.2UF; C_0805_2012Metric
C76: 1UF; C_0805_2012Metric
D3, D4, D5, D6, D7, D8, D9, D10: LED; LED_1206_3216Metric_Pad1.42x1.75mm_HandSolder
J19, J20: DISP_CONN; IDC-Header_2x12_P2.54mm_Vertical
R37, R38, R39, R40, R41, R42, R43, R44: 1.5K; R_0805_2012Metric
R64, R65, R66, R90, R91, R92, R93, R94: 10K; R_0805_2012Metric
R95: 900K; R_0805_2012Metric
SJ2: 12V - SORT; SolderJumper-2_P1.3mm_Open_Pad1.0x1.5mm
SW1, SW2, SW3, SW4, SW5, SW6, SW7, SW8: SW_Push; SW_Push_1P1T_NO_6x6mm_H9.5mm
U5: Hirose_FH12-24S-0.5SH_1x24-1MP_P0.50mm_Horizontal
U6: L78L12_SOT89; SOT-89-3

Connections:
+3V3: J19.12; also elsewhere on the board
+3V3_IN: C76.2, J20.12, R64.2, R65.2, R66.2, R90.2, R91.2, R92.2, R93.2, R94.2, U5.3 (VDD)
+24V: J19.15; also elsewhere on the board
DISP_CS: J19.14; also elsewhere on the board
DISP_CS_D: J20.14, U5.7 (CS)
DISP_D/C: J19.16; also elsewhere on the board
DISP_D/C_D: J20.16, U5.9 (D/C)
DISP_RES: J19.9; also elsewhere on the board
DISP_RES_D: J20.9, U5.8 (RES)
DISP_SPI_MOSI: J19.11; also elsewhere on the board
DISP_SPI_SCK: J19.10; also elsewhere on the board
GND: J19.13; also elsewhere on the board
GND_D: C39.1, C68.1, C69.1, C70.1, C71.1, C72.1, C73.1, C74.1, C75.1, C76.1, C77.1, D3.1 (K), D4.1 (K), D5.1 (K), D6.1 (K), D7.1 (K), D8.1 (K), D9.1 (K), D10.1 (K), J20.13, R95.1, SW1.2, SW2.2, SW3.2, SW4.2, SW5.2, SW6.2, SW7.2, SW8.2, U5.1 (VSS), U5.4 (BS0), U5.5 (BS1), U5.6 (BS2), U5.10 (W/R), U5.11 (R/D), U5.15 (D3), U5.16 (D4), U5.17 (D5), U5.18 (D6), U5.19 (D7), U5.23 (VSS), U5.MP (GND), U6.2 (GND)
LED1: J19.1; also elsewhere on the board
LED1D: J20.1, R37.2
LED2: J19.2; also elsewhere on the board
LED2D: J20.2, R38.2
LED3: J19.3; also elsewhere on the board
LED3D: J20.3, R39.2
LED4: J19.4; also elsewhere on the board
LED4D: J20.4, R40.2
LED5: J19.5; also elsewhere on the board
LED5D: J20.5, R41.2
LED6: J19.6; also elsewhere on the board
LED6D: J20.6, R42.2
LED7: J19.7; also elsewhere on the board
LED7D: J20.7, R43.2
LED8: J19.8; also elsewhere on the board
LED8D: J20.8, R44.2
unnamed: D3.2 (A), R37.1
unnamed: D4.2 (A), R38.1
unnamed: D5.2 (A), R39.1
unnamed: D6.2 (A), R40.1
unnamed: D7.2 (A), R41.1
unnamed: D8.2 (A), R42.1
unnamed: D9.2 (A), R43.1
unnamed: D10.2 (A), R44.1
unnamed: R95.2, U5.20 (IREF)
unnamed: C75.2, U5.21 (VCOMH)
SPI_MOSI_D: J20.11, U5.13 (D1)
SPI_SCK_D: J20.10, U5.12 (D0)
SW_1: J19.24; also elsewhere on the board
SW_1D: C39.2, J20.24, R64.1, SW1.1
SW_2: J19.23; also elsewhere on the board
SW_2D: C68.2, J20.23, R65.1, SW2.1
SW_3: J19.22; also elsewhere on the board
SW_3D: C69.2, J20.22, R66.1, SW3.1
SW_4: J19.21; also elsewhere on the board
SW_4D: C70.2, J20.21, R90.1, SW4.1
SW_5: J19.20; also elsewhere on the board
SW_5D: C71.2, J20.20, R91.1, SW5.1
SW_6: J19.19; also elsewhere on the board
SW_6D: C72.2, J20.19, R92.1, SW6.1
SW_7: J19.18; also elsewhere on the board
SW_7D: C73.2, J20.18, R93.1, SW7.1
SW_8: J19.17; also elsewhere on the board
SW_8D: C74.2, J20.17, R94.1, SW8.1
VDD: C77.2, SJ2.1 (A), U5.2 (VCC), U5.22 (VCC), U6.1 (OUT)
VDD_IN: J20.15, SJ2.2 (B), U6.3 (IN)

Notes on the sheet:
20 X 4 DISPLAY ON TOP 8 KEYS 8 LEDS
NOTE - DISPLAY VDD MAX 16V USE A REGULATOR FOR 24V SUPPLY USE NONE FOR 12V SUPPLY

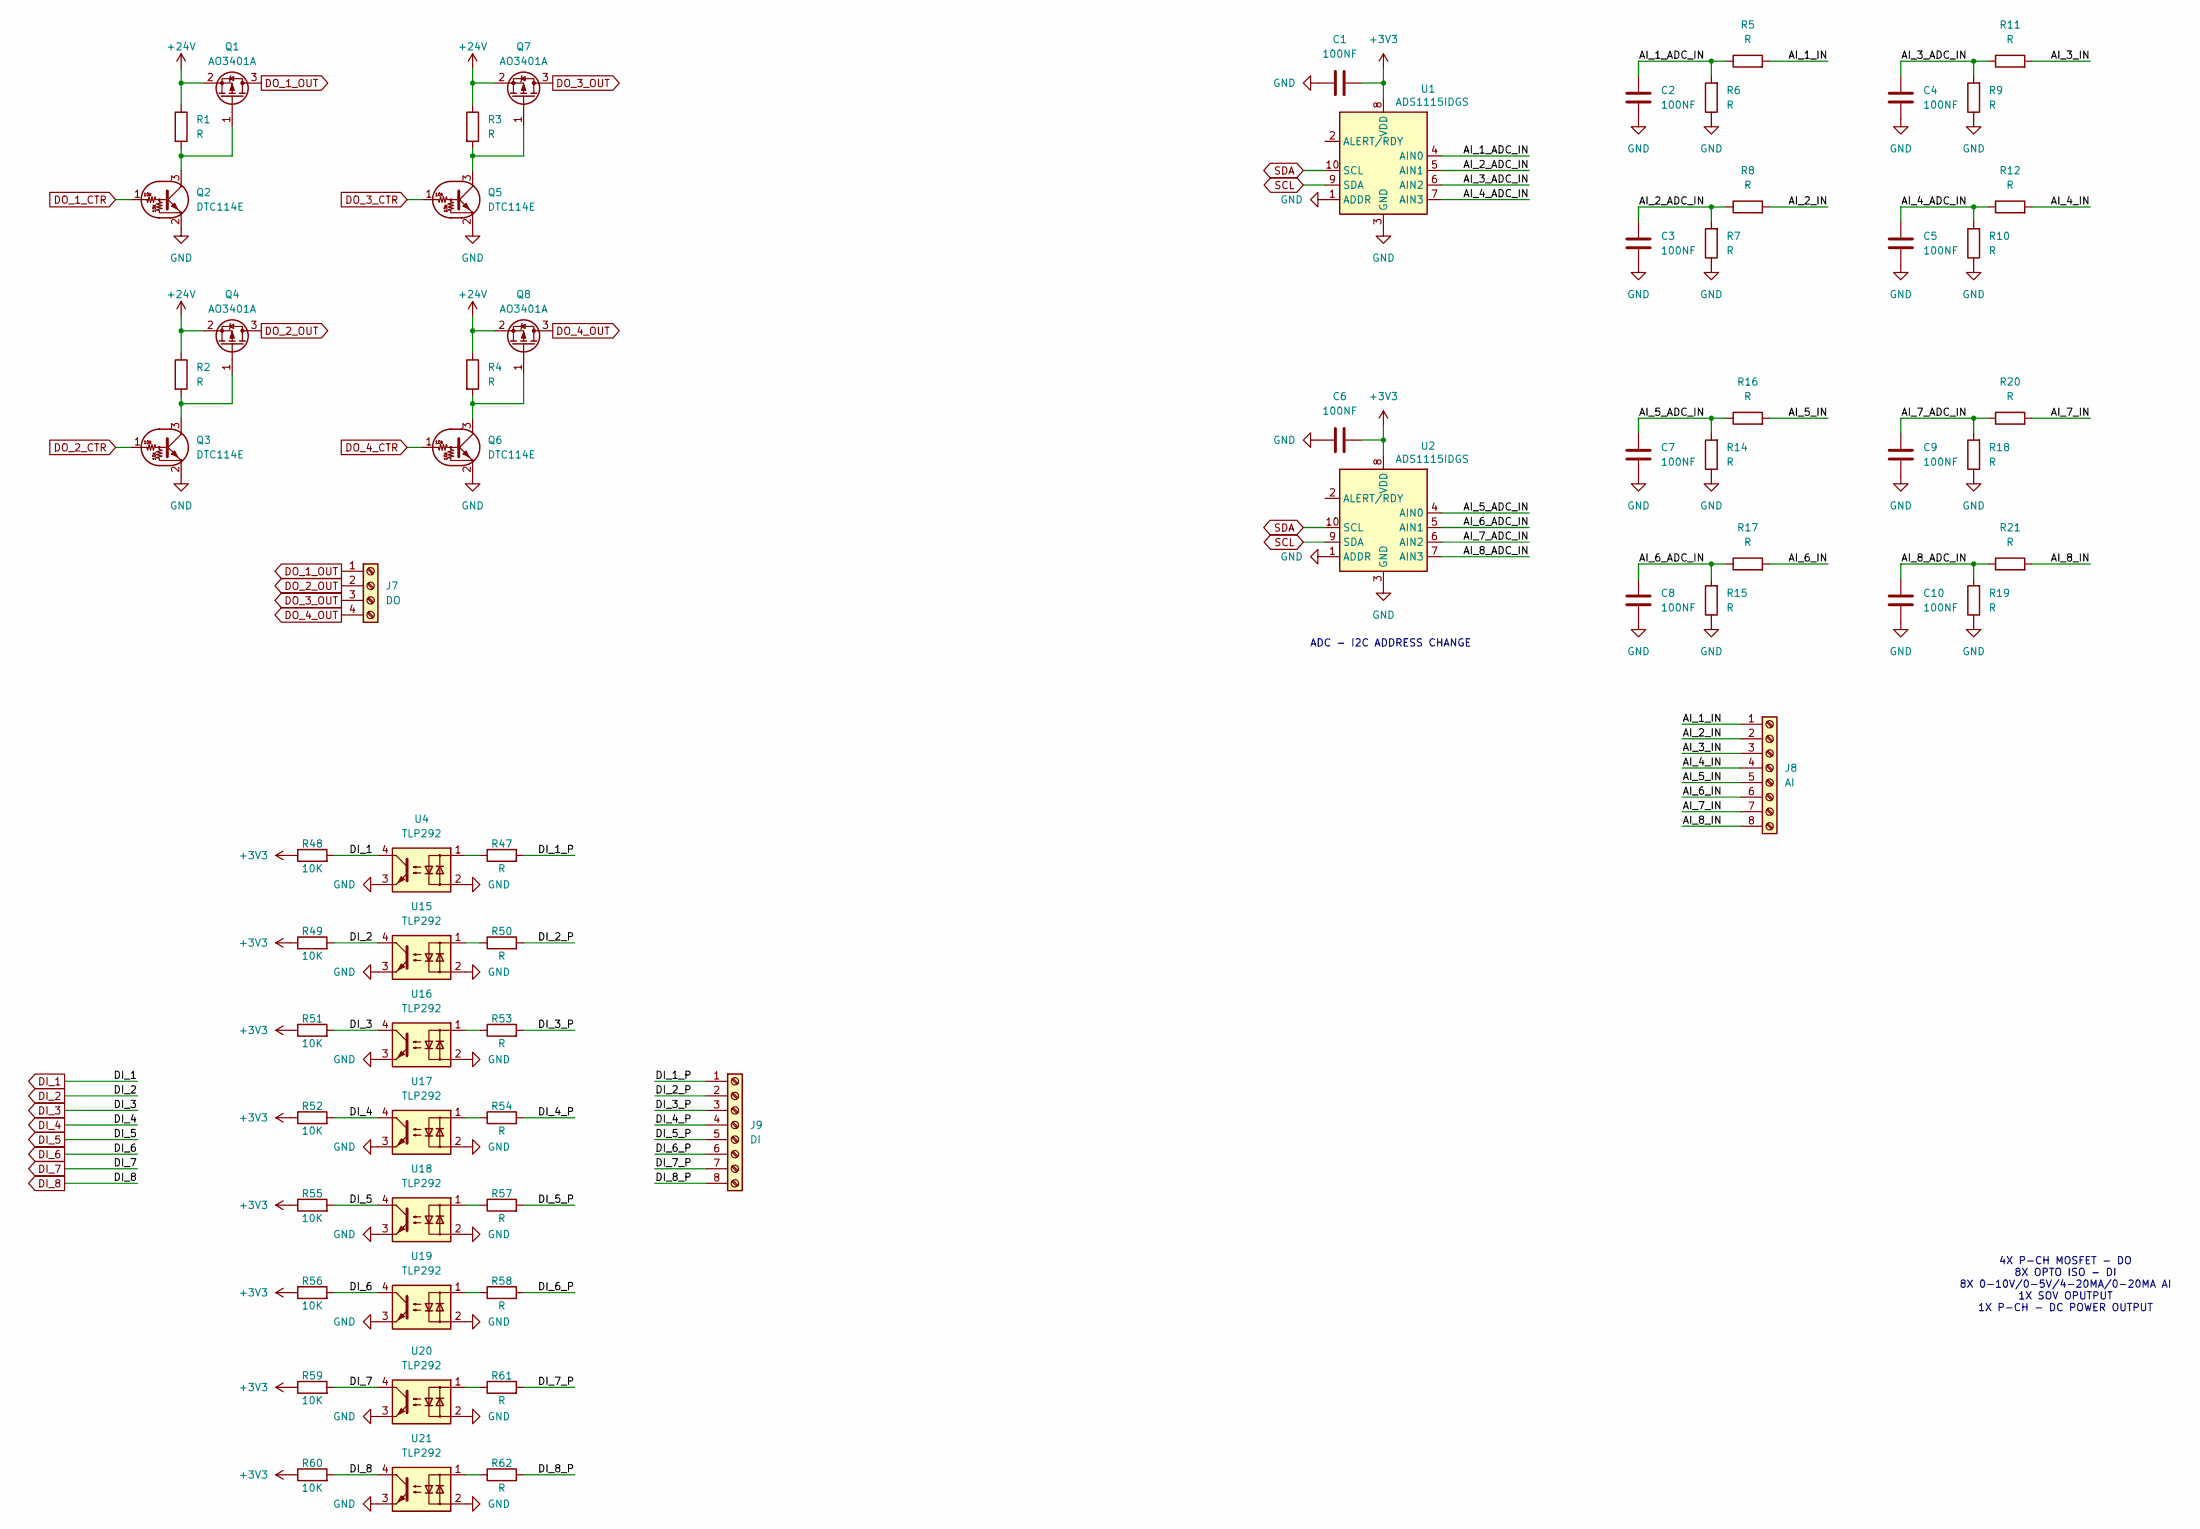
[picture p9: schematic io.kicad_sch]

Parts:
C1, C2, C3, C4, C5, C6, C7, C8, C9, C10: 100NF; C_0805_2012Metric
J7: DO; TerminalBlock_Phoenix_MKDS-3-4-5.08_1x04_P5.08mm_Horizontal
J8: AI; TerminalBlock_Phoenix_MKDS-3-8-5.08_1x08_P5.08mm_Horizontal
J9: DI; TerminalBlock_Phoenix_MKDS-3-8-5.08_1x08_P5.08mm_Horizontal
Q1, Q4, Q7, Q8: AO3401A; SOT-23
Q2, Q3, Q5, Q6: DTC114E; SOT-23
R1, R2, R3, R4, R5, R6, R7, R8, R9, R10, R11, R12, R14, R15, R16, R17, R18, R19, R20, R21, R47, R50, R53, R54, R57, R58, R61, R62: R; R_0805_2012Metric
R48, R49, R51, R52, R55, R56, R59, R60: 10K; R_0805_2012Metric
U1, U2: ADS1115IDGS; TSSOP-10_3x3mm_P0.5mm
U4, U15, U16, U17, U18, U19, U20, U21: TLP292; SOIC-4_4.55x2.6mm_P1.27mm

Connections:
+3V3: C1.1, C6.1, R48.1, R49.1, R51.1, R52.1, R55.1, R56.1, R59.1, R60.1, U1.8 (VDD), U2.8 (VDD); also elsewhere on the board
+24V: Q1.2 (S), Q4.2 (S), Q7.2 (S), Q8.2 (S), R1.1, R2.1, R3.1, R4.1; also elsewhere on the board
/IO/AI_1_ADC_IN: C2.1, R5.1, R6.2, U1.4 (AIN0)
/IO/AI_1_IN: J8.1, R5.2
/IO/AI_2_ADC_IN: C3.1, R7.2, R8.1, U1.5 (AIN1)
/IO/AI_2_IN: J8.2, R8.2
/IO/AI_3_ADC_IN: C4.1, R9.2, R11.1, U1.6 (AIN2)
/IO/AI_3_IN: J8.3, R11.2
/IO/AI_4_ADC_IN: C5.1, R10.2, R12.1, U1.7 (AIN3)
/IO/AI_4_IN: J8.4, R12.2
/IO/AI_5_ADC_IN: C7.1, R14.2, R16.1, U2.4 (AIN0)
/IO/AI_5_IN: J8.5, R16.2
/IO/AI_6_ADC_IN: C8.1, R15.2, R17.1, U2.5 (AIN1)
/IO/AI_6_IN: J8.6, R17.2
/IO/AI_7_ADC_IN: C9.1, R18.2, R20.1, U2.6 (AIN2)
/IO/AI_7_IN: J8.7, R20.2
/IO/AI_8_ADC_IN: C10.1, R19.2, R21.1, U2.7 (AIN3)
/IO/AI_8_IN: J8.8, R21.2
/IO/DI_1_P: J9.1, R47.2
/IO/DI_2_P: J9.2, R50.2
/IO/DI_3_P: J9.3, R53.2
/IO/DI_4_P: J9.4, R54.2
/IO/DI_5_P: J9.5, R57.2
/IO/DI_6_P: J9.6, R58.2
/IO/DI_7_P: J9.7, R61.2
/IO/DI_8_P: J9.8, R62.2
DI_1: R48.2, U4.4; also elsewhere on the board
DI_2: R49.2, U15.4; also elsewhere on the board
DI_3: R51.2, U16.4; also elsewhere on the board
DI_4: R52.2, U17.4; also elsewhere on the board
DI_5: R55.2, U18.4; also elsewhere on the board
DI_6: R56.2, U19.4; also elsewhere on the board
DI_7: R59.2, U20.4; also elsewhere on the board
DI_8: R60.2, U21.4; also elsewhere on the board
DO_1_CTR: Q2.1 (B); also elsewhere on the board
DO_1_OUT: J7.1, Q1.3 (D)
DO_2_CTR: Q3.1 (B); also elsewhere on the board
DO_2_OUT: J7.2, Q4.3 (D)
DO_3_CTR: Q5.1 (B); also elsewhere on the board
DO_3_OUT: J7.3, Q7.3 (D)
DO_4_CTR: Q6.1 (B); also elsewhere on the board
DO_4_OUT: J7.4, Q8.3 (D)
GND: C1.2, C2.2, C3.2, C4.2, C5.2, C6.2, C7.2, C8.2, C9.2, C10.2, Q2.2 (E), Q3.2 (E), Q5.2 (E), Q6.2 (E), R6.1, R7.1, R9.1, R10.1, R14.1, R15.1, R18.1, R19.1, U1.1 (ADDR), U1.3 (GND), U2.1 (ADDR), U2.3 (GND), U4.2, U4.3, U15.2, U15.3, U16.2, U16.3, U17.2, U17.3, U18.2, U18.3, U19.2, U19.3, U20.2, U20.3, U21.2, U21.3; also elsewhere on the board
unnamed: Q1.1 (G), Q2.3 (C), R1.2
unnamed: Q3.3 (C), Q4.1 (G), R2.2
unnamed: Q5.3 (C), Q7.1 (G), R3.2
unnamed: Q6.3 (C), Q8.1 (G), R4.2
unnamed: R47.1, U4.1
unnamed: R50.1, U15.1
unnamed: R53.1, U16.1
unnamed: R54.1, U17.1
unnamed: R57.1, U18.1
unnamed: R58.1, U19.1
unnamed: R61.1, U20.1
unnamed: R62.1, U21.1
SCL: U1.9 (SDA), U2.9 (SDA); also elsewhere on the board
SDA: U1.10 (SCL), U2.10 (SCL); also elsewhere on the board

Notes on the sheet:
4X P-CH MOSFET - DO 8X OPTO ISO - DI 8X 0-10V/0-5V/4-20MA/0-20MA AI 1X SOV OPUTPUT 1X P-CH - DC POWER OUTPUT
ADC - I2C ADDRESS CHANGE

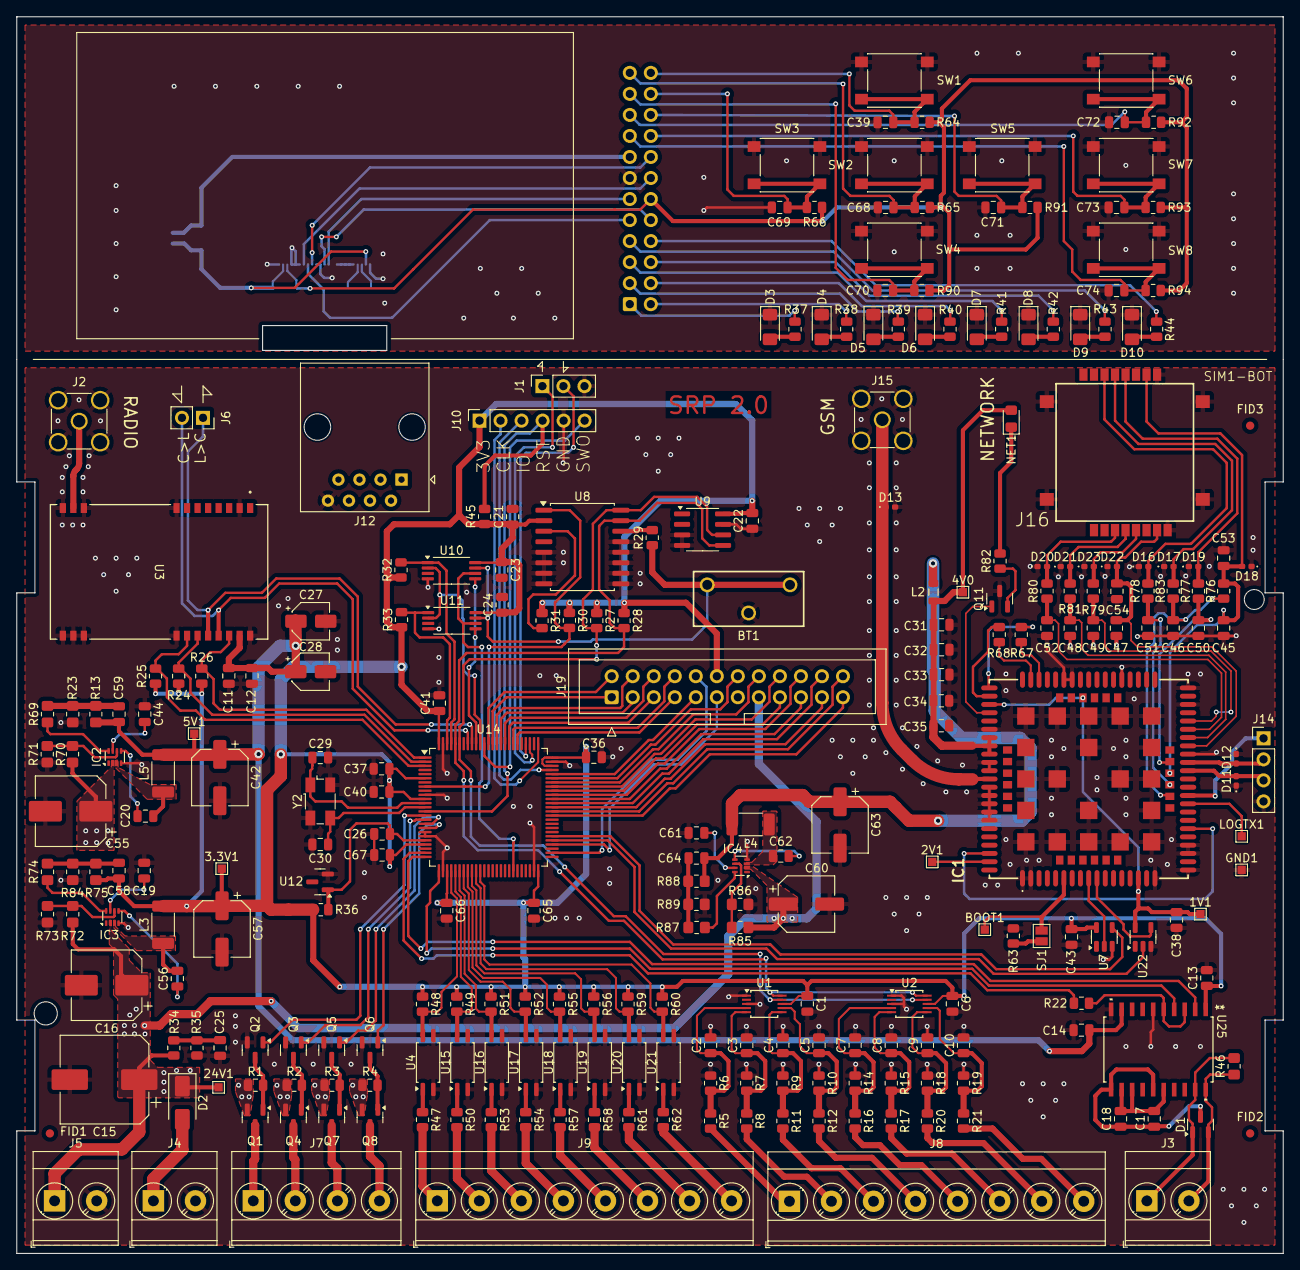
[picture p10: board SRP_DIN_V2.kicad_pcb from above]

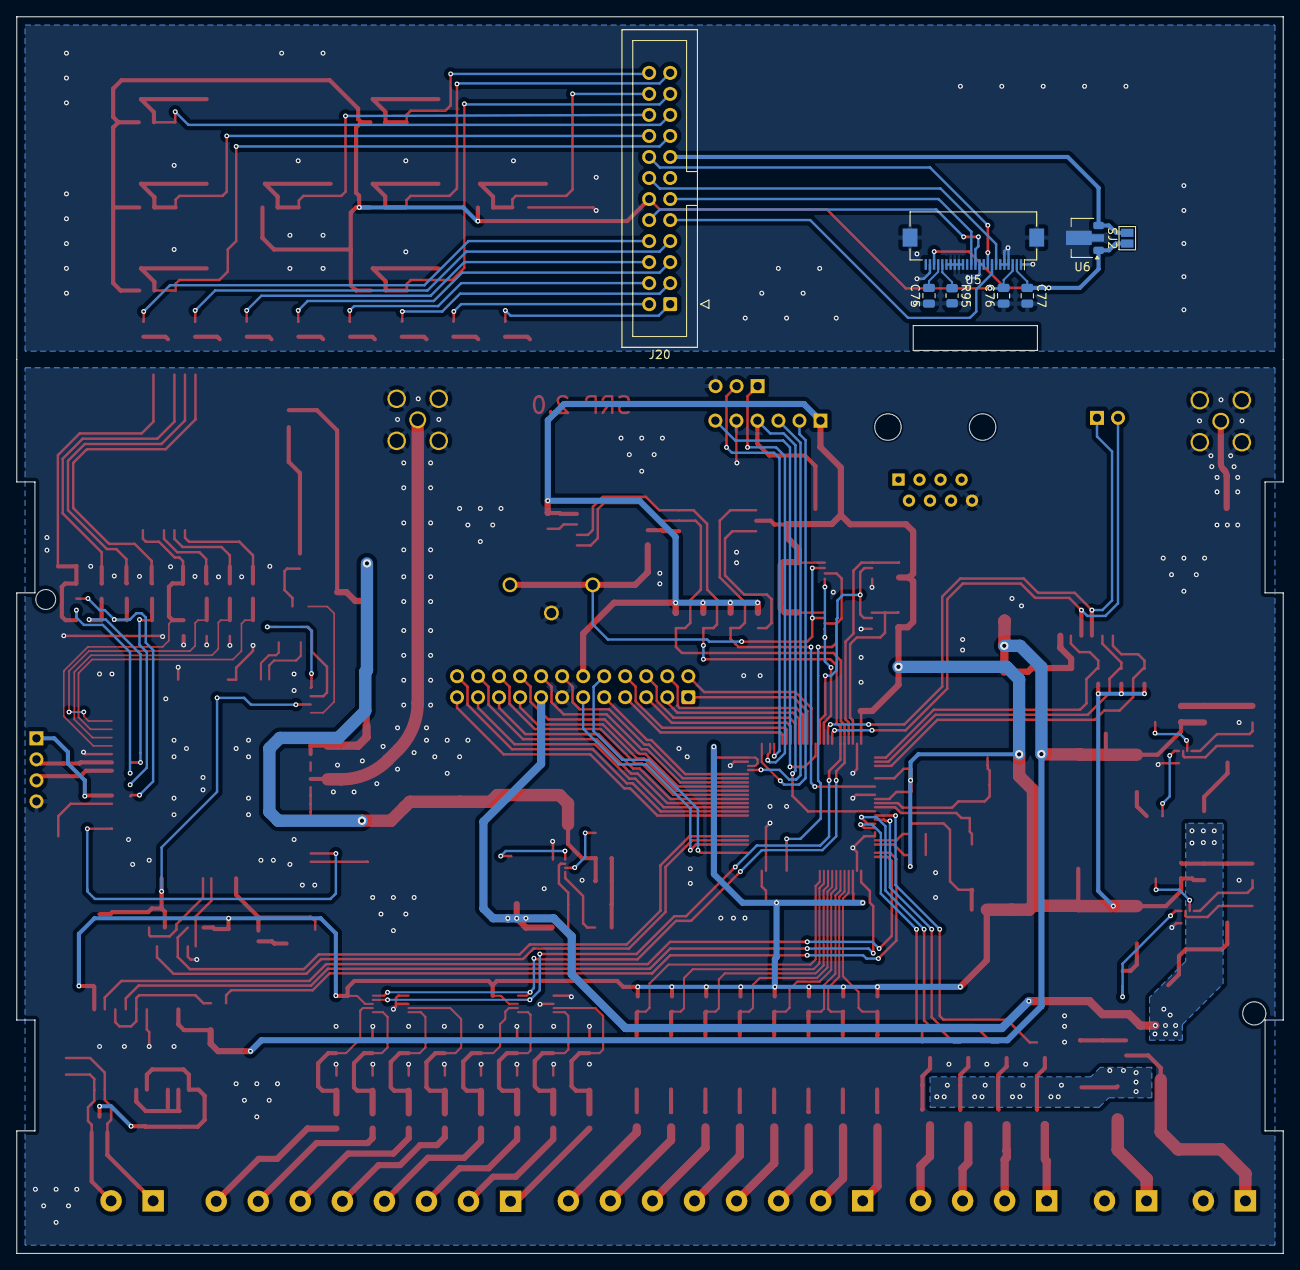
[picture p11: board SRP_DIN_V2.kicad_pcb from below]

Board: 2 copper layers, 153.0 x 149.4 mm, 273 parts (8 on the bottom side), 203 nets.
